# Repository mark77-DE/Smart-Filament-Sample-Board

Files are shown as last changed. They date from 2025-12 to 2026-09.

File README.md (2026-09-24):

<p align="center">
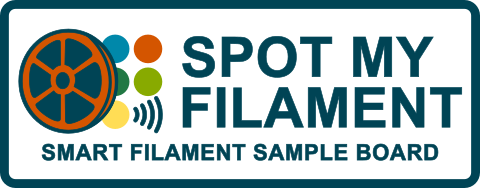
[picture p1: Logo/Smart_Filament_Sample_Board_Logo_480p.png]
Smart Filament Sample Board Logo
  
</p>

<h1 align="center">Smart Filament Sample Board</h1>
<p align="center"><i>Spot My Filament — finde jedes Filament-Sample per NFC-Tag auf einen Blick.</i></p>

<p align="center">
  
  
  
</p>

<p align="center">
  🇩🇪 <strong>Deutsch</strong> &nbsp;|&nbsp; 🇬🇧 <a href="./README_EN.md">English</a>
</p>

---

## Inhaltsverzeichnis

* [Funktionsweise](#funktionsweise)
* [Benötigte Hardware](#benötigte-hardware)
* [Galerie](#galerie)
* [Erste Schritte](#erste-schritte)
* [Dokumentation](#dokumentation)
* [Mitmachen](#mitmachen)
* [Lizenz](#lizenz)

## Funktionsweise

Workflow basierend auf einer eigenen JSON-Datenbank auf dem ESP32:

1. NFC-Tag wird über den NFC-Reader gelesen.
2. Der ESP32 fragt die Datenbank ab und stellt die Daten auf dem Display dar.
3. Die entsprechende LED leuchtet auf und zeigt den Lagerplatz des Samples an.
4. Ein Klick im WebIF zeigt ebenfalls, wo das Filament-Sample lagert.

Zusätzlich gibt es eine Anbindung an **Home Assistant** via HA-Discovery und MQTT:

Der ESP32 sendet das ausgewählte Filament (per NFC-Tag oder Klick im WebIF) an Home Assistant. LEDs und Display lassen sich per HA ein-/ausschalten, der ESP übermittelt den Status zurück.

## Benötigte Hardware

Siehe [Hardware-Dokumentation](./docs/hardware.md).

## Galerie

<p align="center">
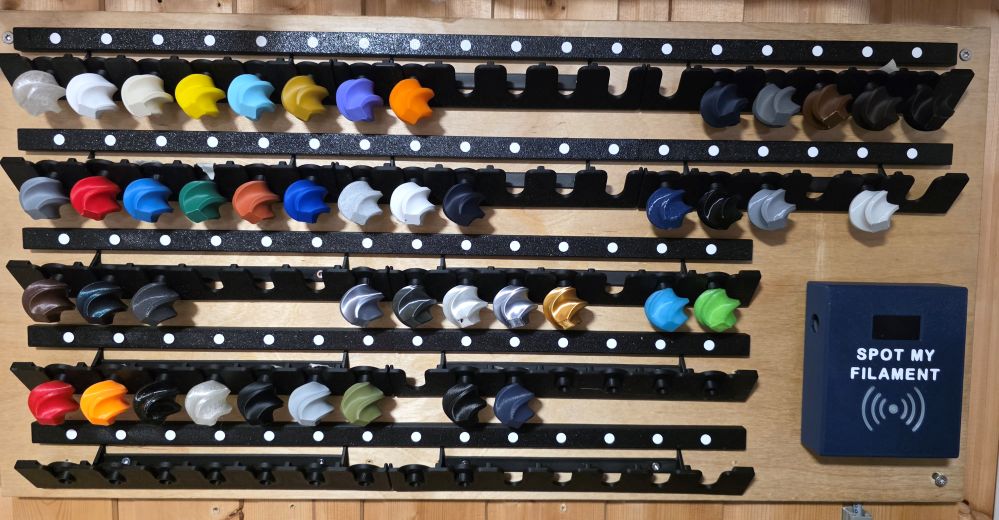
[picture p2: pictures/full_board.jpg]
Fertiges Board
  
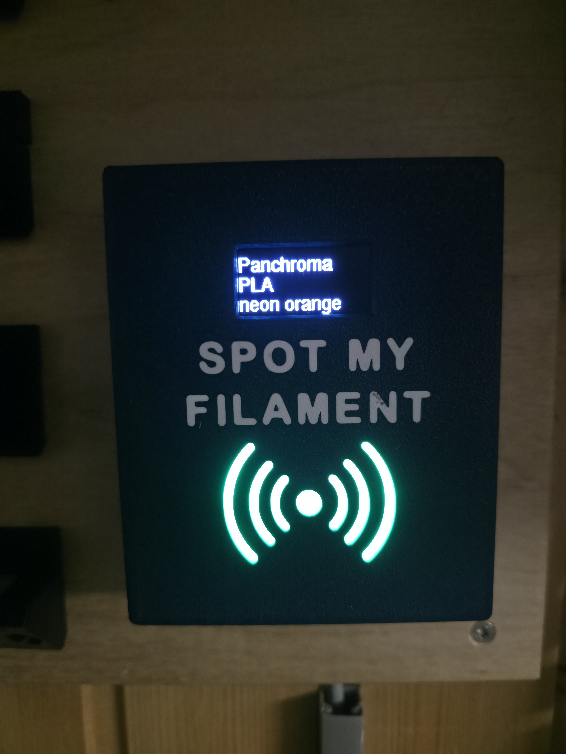
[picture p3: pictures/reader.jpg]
Display/Reader
    
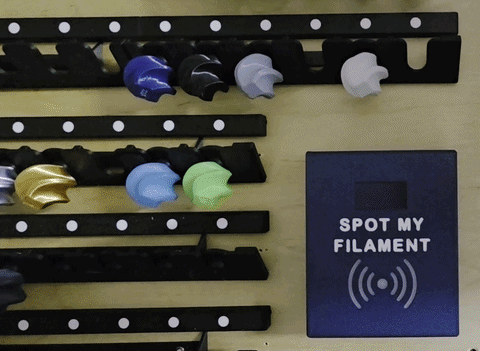
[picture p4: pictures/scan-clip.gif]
  <br>
  <sub>Fertig aufgebautes Board</sub>
</p>

<p align="center">
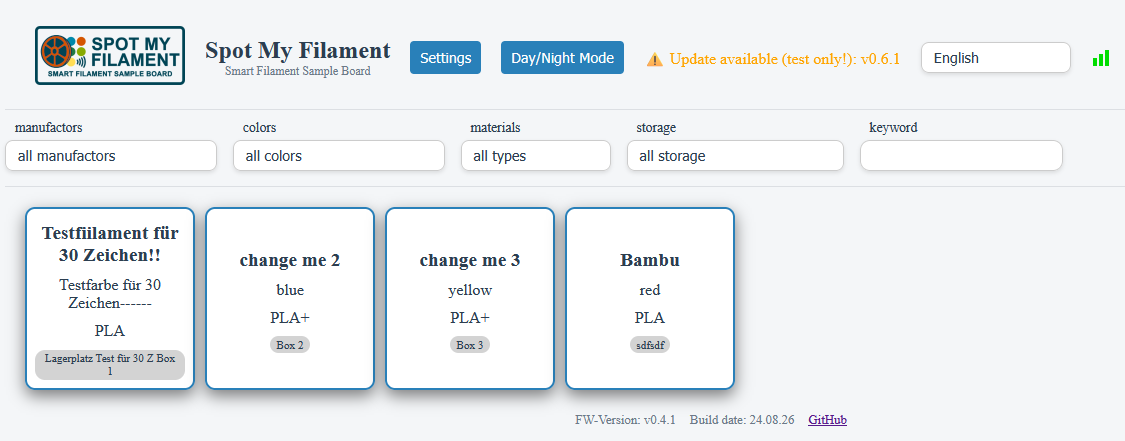
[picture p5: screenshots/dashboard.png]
Dashboard Daymode
  
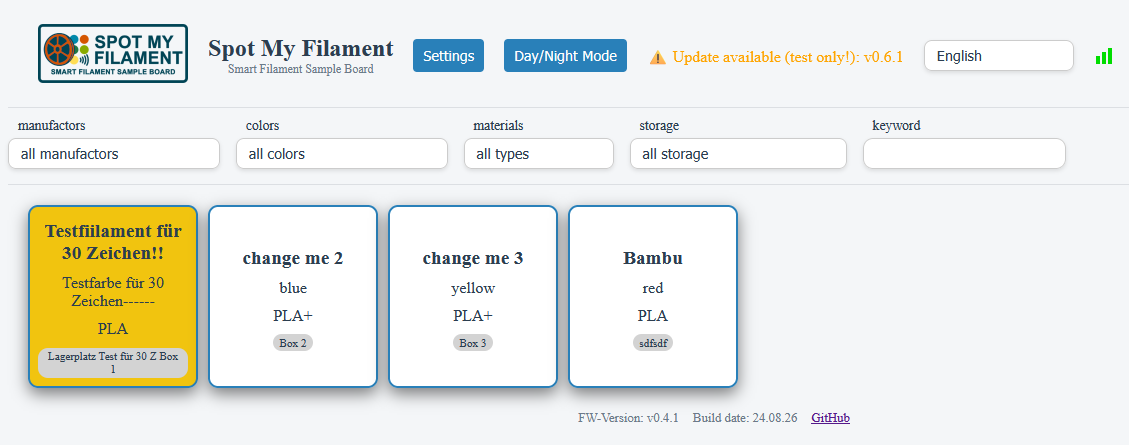
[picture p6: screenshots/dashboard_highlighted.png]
Dashboard Highlighted
  <br>
  <sub>Home-Assistant-Dashboard: Übersicht (links) und markiertes Sample (rechts)</sub>
</p>

## Erste Schritte

Kurzfassung — die ausführliche Anleitung steht in [`docs/setup.md`](docs/setup.md).

1. Hardware gemäß [`docs/hardware.md`](docs/hardware.md) verdrahten.
2. Firmware aus [`ESP32-Webserver`](ESP32-Webserver) auf den ESP32 flashen (siehe [`docs/setup.md`](docs/setup.md)).
3. WLAN-Zugangsdaten konfigurieren.
4. Optional: MQTT und Home-Assistant-Integration aktivieren (Auto-Discovery).
5. NFC-Tags anlegen und Filament-Samples zuordnen, siehe [`docs/usage.md`](docs/usage.md).

## Dokumentation

Ausführliche Anleitungen findest du im [`docs/`](docs) Ordner:

| Dokument | Inhalt |
| --- | --- |
| [`docs/hardware.md`](docs/hardware.md) | Verkabelung, Pinbelegung, Schaltplan |
| [`docs/setup.md`](docs/setup.md) | Firmware flashen, Konfiguration, Home-Assistant-Setup |
| [`docs/usage.md`](docs/usage.md) | Alltägliche Bedienung, NFC-Tags anlegen, WebIF |
| [`docs/3d-print.md`](docs/3d-print.md) | 3D-Druckteile aus [`3D-Daten`](3D-Daten), Druckeinstellungen |

<!-- Sammlung offener Notizen/Ideen liegt aktuell in Notes/ – ggf. dort verlinken -->

## Mitmachen

Contributions, Issues und Feature-Wünsche sind willkommen!

Schau gerne im [Issues-Tab](https://github.com/mark77-DE/Smart-Filament-Sample-Board/issues) vorbei.

<!-- TODO: falls gewünscht, CONTRIBUTING.md ergänzen und hier verlinken -->

## Lizenz

Dieses Projekt steht unter der [GPL-3.0 Lizenz](LICENSE).

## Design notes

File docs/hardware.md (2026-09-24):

# Hardware & Verkabelung

Diese Seite beschreibt den Aufbau des Smart Filament Sample Boards.

## Stückliste

| Komponente | Menge | Hinweise | Links |
|---|---|---|---|
| ESP-32 Devkit V1 **oder** ESP32-S3 Super Mini | 1 | | |
| PN532 NFC-Reader | 1 | | |
| WS2812B **oder**<br>SK6812 **oder**<br>SK6812W LEDs | 4×3 (Standard) NFC-Symbol<br>Plus Anzahl Samples | für Hintergrundbeleuchtung des NFC Symbols,<br> laut KI bis 150 LEDs je nach eigenem Setup<br>Abstand der LEDs sollte 33mm betragen, also 30LEDs/m | |
| 1.3" I2C Display 128×64 SH1106 **oder** 1.9" TFT ST7789 | 1 | | |
| Taster | optional | | |
| Buzzer | optional | | |
| Ntag215 | bis 150 | DieStückzahl sollte min. zur Anzahl der geplanten Samples passen | [AliExpress](https://de.aliexpress.com/item/1005006375989905.html) |
| Netzteil | 1 | <!-- TODO: Spannung/Stromstärke --> | |

## Pinbelegung

Die Pinbelegung ist, je nach verwendeten Controllertyp und Display, unterschiedlich.
Für die kompilierten Binaries gibt es feste Vorgaben, wer selbst kompiliert, kann das in der platformio.ini entsprechend modifizieren.

Für den weit verbreiteten Standard typ, dem ESP32 Devkit V1 gillt folgendes pinout:

### ESP32 OLED Variante
| ESP32 Pin | Verbunden mit | Funktion |
|---|---|---|
| GPIO 4 | LEDs | Samples |
| GPIO 15 | LEDs | NFC-Symbol |
| GPIO 18 | SPI/SCK | NFC-Reader |
| GPIO 19 | SPI/MISO | NFC-Reader |
| GPIO 21 | SDA | OLED |
| GPIO 22 | SCL | OLED |
| GPIO 23 | SPI/MOSI | NFC-Reader |
| GPIO 26 | PN532 CS | NFC-Reader |
| GPIO 32 | Button | optional |
| GPIO 33 | Buzzer | optional |

### ESP32-S3 OLED Variante
*(getestet mit ESP32-S3 Zero)*

| ESP32-S3 Pin | Verbunden mit | Funktion |
|---|---|---|
| GPIO 1 | LEDs | NFC-Symbol |
| GPIO 2 | LEDs | Samples |
| GPIO 3 | SPI/SCK | NFC-Reader |
| GPIO 4 | SPI/MISO | NFC-Reader |
| GPIO 5 | SPI/MOSI | NFC-Reader |
| GPIO 6 | PN532 CS | NFC-Reader |
| GPIO 7 | Button | optional |
| GPIO 8 | Buzzer | optional |
| GPIO 12 | SCL | OLED |
| GPIO 13 | SDA | OLED |

### ESP32 ST7789 Variante
| ESP32 Pin | Verbunden mit | Funktion |
|---|---|---|
| GPIO 4 | LEDs | Samples |
| GPIO 5 | TFT CS | ST7789 Display |
| GPIO 12 | NFC_MISO | NFC-Reader |
| GPIO 13 | NFC_MOSI | NFC-Reader |
| GPIO 14 | NFC_SCK | NFC-Reader |
| GPIO 15 | LEDs | NFC-Symbol |
| GPIO 26 | PN532 CS | NFC-Reader |
| GPIO 27 | TFT RST | ST7789 Display |
| GPIO 32 | TFT DC | ST7789 Display |
| GPIO 33 | Buzzer | optional |

### ESP32-S3 ST7789 Variante
| ESP32 Pin | Verbunden mit | Funktion |
|---|---|---|
| GPIO 4 | LEDs | Samples |
| GPIO 5 | TFT CS | ST7789 Display |
| GPIO 12 | NFC_MISO | NFC-Reader |
| GPIO 13 | NFC_MOSI | NFC-Reader |
| GPIO 14 | NFC_SCK | NFC-Reader |
| GPIO 15 | LEDs | NFC-Symbol |
| GPIO 25 | Button | optional |
| GPIO 26 | PN532 CS | NFC-Reader |
| GPIO 27 | TFT RST | ST7789 Display |
| GPIO 32 | TFT DC | ST7789 Display |
| GPIO 33 | Buzzer | optional |
| – | TFT MISO | nicht verbunden |

## Schaltplan / Wiring-Diagramm

<!-- TODO: Bild einbinden, z. B. aus Fritzing oder handgezeichnet
![Wiring Diagram](../pictures/wiring.png)
-->

## Aufbauhinweise

<!-- TODO: Besonderheiten beim Zusammenbau, z. B.:
- Reihenfolge der LED-Kette
- Stromversorgung bei vielen LEDs (separates Netzteil? Sicherung?)
- Gehäuse / mechanischer Aufbau, Verweis auf 3D-Daten
-->

Optimalfall: Das Netzteil sollte von der Leistung her zur Anzahl der LEDs passen wobei jede LED max. 60mA ziehen könnte..
Relaistisch (ohne Garantie): Durch die Limitierung der Brightness und der Tatsache, dass nie alle LEDs zeitgleich leuchten, kann das Netzteil auch kleiner ausgeführt werden. Für eine Testaufbau mit z.B. 16 LEDs reicht die Versorgung über edn ESP völlig aus.

Siehe auch: [`3d-print.md`](3d-print.md) für die gedruckten Gehäuseteile.

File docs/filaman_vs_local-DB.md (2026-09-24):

# Workflow: Lokale DB (filaments.json) vs. FilaMan-DB

Diese Seite beschreibt, wann das Smart Filament Sample Board auf die **lokale
`filaments.json`** (LittleFS) zugreift und wann es live gegen die
**FilaMan-API** abfragt — inklusive Sync-Mechanismus.

## Grundprinzip

| | Lokale DB (`filaments.json`) | FilaMan-DB (live) |
|---|---|---|
| Quelle | LittleFS auf dem ESP32 | FilaMan-Server (`server-ip:port`) |
| Inhalt | vendor, type, color, ledIndex, info1 (Bestand), info2 (Shop-URL) | Alle Felder inkl. `storage` (Lagerort) |
| Aktualisierung | Manuelle Pflege per WebIF | Immer aktuell (Live-Abfrage) |
| Geschwindigkeit | Sehr schnell (lokal) | Abhängig von Netzwerk/API-Latenz |
| Warum getrennt? | Stabile Stammdaten, selten geändert | Lagerort ändert sich häufig (AMS/Bambuddy-Zuordnung) und wäre in lokaler DB schnell veraltet |

Der Lagerort (`storage`) wird bewusst **nicht** synchronisiert, sondern immer
live abgefragt, da er sich zu oft ändert.

## Workflow 1: NFC-Scan am Sample Board (Nutzung)

```mermaid
flowchart TD
    A[Nutzer scannt NFC-Tag am Sample Board] --> B{sampleboard_uid bekannt?}
    B -- "Nein" --> Z[Fehleranzeige: UID nicht gefunden]
    B -- "Ja, in lokaler DB" --> C[Lade Stammdaten aus filaments.json:<br/>vendor, type, color, ledIndex, info1, info2]
    C --> D[LED am ledIndex ansteuern]
    C --> E{Netzwerk verfügbar?}
    E -- "Nein" --> F[Anzeige nur mit Stammdaten<br/>Lagerort: 'nicht verfügbar']
    E -- "Ja" --> G[Live-Query an FilaMan:<br/>filament_id -> zugehörige Spulen -> Lagerorte]
    G --> H[Lagerorte aggregieren<br/>sortiert nach Restbestand]
    H --> I[Vollständige Anzeige:<br/>Stammdaten + aktueller Lagerort]
```

**Kernidee:** Die lokale DB liefert sofort die stabilen Anzeigedaten und
steuert die LED, unabhängig vom Netzwerk. Der Lagerort wird nur bei
Bedarf live nachgeladen und ergänzt die Anzeige, sobald er verfügbar ist.

## Workflow 2: Sync der lokalen DB (Wartung)

```mermaid
flowchart TD
    A[Nutzer löst Sync aus<br/>WebIF-Button oder Hardware-Taste] --> B[Login an FilaMan-API<br/>POST /auth/login -> Cookie session_id]
    B --> C[GET /api/v1/filaments<br/>alle Filamente mit gesetztem sampleboard_uid]
    C --> D[Für jedes Filament Custom-Field<br/>sampleboard_led auslesen -> ledIndex]
    D --> E[Für jedes Filament zugehörige Spulen<br/>abfragen: Anzahl + Restgewicht summieren]
    E --> F[Feld-Mapping:<br/>vendor = manufacturer.name<br/>type = material_type<br/>color = manufacturer_color_name<br/>info1 = 'X Spulen mit Y g Restgewicht'<br/>info2 = shop_url]
    F --> G[filaments.json auf LittleFS schreiben/überschreiben]
    G --> H[Sync abgeschlossen -> Bestätigung im WebIF]
```

**Wichtig:** Der Sync läuft **nicht automatisch** bei jedem Boot, sondern nur
auf explizite Nutzeranforderung, um unnötige API-Last und Inkonsistenzen zu
vermeiden.

## Entscheidungslogik im Code (Kurzfassung)

```mermaid
flowchart LR
    A[UID gescannt] --> B[Lookup in filaments.json]
    B --> C[Stammdaten + LED sofort]
    C --> D{Storage-Info gewünscht?}
    D -- "Ja" --> E[Live-Call FilaMan]
    D -- "Nein / offline" --> F[Fertig ohne Lagerort]
    E --> G[Fertig mit Lagerort]
```

## Offene Punkte

- Workaround für den FilaMan-Bug bei der Custom-Field-Suche auf
  `/api/v1/filaments` bleibt bestehen, bis der Fix im Upstream-Projekt
  gemergt ist.

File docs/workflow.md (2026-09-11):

# Dev- & Release-Workflow — Smart Filament Sample Board

## Überblick

Zwei getrennte Pfade:

- **`dev_release.py`** — lokale Testbuilds, OTA Self-Update gegen einen simulierten Testserver, kein Git-Tag, kein GitHub Release.
- **`release.py`** — echtes, öffentliches Release (Git-Tag, GitHub Pre-/Release, Webinstaller-Update).

Versionsnummern werden **nicht** manuell gepflegt, sondern automatisch von `tools/git_version.py` erzeugt (läuft als PlatformIO `pre:`-Script bei jedem Build).

---

## 1. Entwickeln auf `dev` (oder einem Feature-Branch)

Normal weiterarbeiten, committen wie gewohnt.

```bash
git switch dev
# ... Änderungen ...
git add .
git commit -m "..."
```

Feature-Branches (z. B. `display`) zweigen von `dev` ab und funktionieren genauso — `dev_release.py` und `git_version.py` erkennen automatisch, dass es kein `main` ist.

---

## 2. Lokal testen mit `dev_release.py`

```bash
python tools/dev_release.py
# oder mit expliziter Test-Server-IP:
python tools/dev_release.py --server-ip 172.16.0.123
python tools/dev_release.py --server-ip 172.16.0.123 --port 8080
```

Was dabei passiert:

1. **Branch-Check**: bricht ab, wenn der aktuelle Branch `main` ist (Sicherheitsnetz, damit nie versehentlich ein "Test"-Build von `main` aus läuft).
2. **`ota_local_server_generated.h`** wird geschrieben (Testserver-IP/-Port), entweder automatisch erkannt oder per `--server-ip` vorgegeben.
3. **Build** der vier `*_dev`-Envs (`esp32_dev`, `esp32-st7789_dev`, `esp32-s3_dev`, `esp32-s3-st7789_dev`) — diese haben zusätzlich `-D OTA_DEBUG_LOCAL_SERVER` gesetzt.
4. **Kopieren** der vier `firmware.bin`-Dateien nach `tools/local_testserver/v9.9.9/` mit festen Namen:
   - `esp32-sh1106-firmware.bin`
   - `esp32-st7789-firmware.bin`
   - `esp32-s3-sh1106-firmware.bin`
   - `esp32-s3-st7789-firmware.bin`

Danach den simulierten Testserver in diesem Ordner starten (z. B. `python -m http.server 8000` in `tools/local_testserver/v9.9.9/`) und am Gerät den OTA Self-Update testen.

`FIRMWARE_VERSION` in diesem Build lautet automatisch z. B. `v0.4.11-dev.3` (auf `dev`) oder `v0.4.11-dev.3-disp` (auf einem Feature-Branch namens `display`).

---

## 3. Release bauen

```bash
git switch main
git merge dev              # WICHTIG: main auf den aktuellen dev-Stand bringen
python tools/release.py 0.4.12
```

`release.py` übernimmt: Git-Tag setzen, Firmware bauen (normale Envs ohne `OTA_DEBUG_LOCAL_SERVER`, also mit der echten GitHub-URL), Webinstaller-Manifeste aktualisieren, GitHub Release erstellen, pushen.

---

## 4. `dev` wieder auf den aktuellen Stand bringen

**Nicht vergessen — sonst zählt `git_version.py` ab dem alten Tag weiter:**

```bash
git switch dev
git merge main
```

Ohne diesen Schritt bleibt der zuletzt getaggte Release-Commit für `dev` unerreichbar, und `git_version.py` fällt auf den vorletzten Tag zurück (z. B. `v0.4.9-dev.N` statt `v0.4.11-dev.N`).

---

## Versionslogik (`tools/git_version.py`)

Läuft bei **jedem** Build (alle Envs, egal ob `release.py` oder `dev_release.py`).

| Branch | `FIRMWARE_VERSION` |
|---|---|
| `main` | exakt der letzte Tag, z. B. `v0.4.11` |
| `dev` | `v0.4.11-dev.N` (N = Commits seit dem letzten *echten* Tag) |
| Feature-Branch (z. B. `display`) | `v0.4.11-dev.N-disp` (Branchname auf 4 Zeichen gekürzt) |

Wichtig: Alte `-dev`-Tags aus dem ursprünglichen Workflow (z. B. `v0.4.11-dev`, `v0.4.12-dev`) werden beim Ermitteln des Basis-Tags bewusst ausgeschlossen (`--exclude "*-dev*"`), damit sie die Zählung nicht verfälschen. Sie können bei Gelegenheit aufgeräumt werden, stören aber nicht mehr:

```bash
git tag -d v0.4.11-dev
git push origin :refs/tags/v0.4.11-dev
```

`STABLE_BRANCH` ist in `git_version.py` als `"main"` hinterlegt — falls der Produktions-Branch anders heißt, dort anpassen.

---

## Beteiligte Dateien

| Datei | Zweck | Wird committet? |
|---|---|---|
| `tools/git_version.py` | Generiert `include/version_info.h` bei jedem Build (Version, Git-Hash, Build-Datum) | Ja |
| `tools/dev_release.py` | Lokaler Testbuild + Kopie nach `local_testserver/` | Ja |
| `tools/release.py` | Echtes Release (Tag, Build, GitHub Release, Webinstaller) | Ja |
| `include/version_info.h` | Auto-generiert, nicht von Hand pflegen | Nein (gitignore) |
| `include/ota_local_server_generated.h` | Auto-generiert von `dev_release.py`, enthält lokale Test-Server-URL | Nein (gitignore) |
| `tools/local_testserver/v9.9.9/` | Ablage der Testbuilds für OTA Self-Update Tests | Nein (gitignore empfohlen) |

`.gitignore`-Einträge, falls noch nicht vorhanden:

```
include/version_info.h
include/ota_local_server_generated.h
tools/local_testserver/
```

---

## platformio.ini — relevante Envs

```ini
; Normale Produktions-Envs (nutzt release.py)
[env:esp32]
...
[env:esp32-st7789]
...
[env:esp32-s3]
...
[env:esp32-s3-st7789]
...

; Dev/Test-Envs (nutzt dev_release.py) — je extends + OTA_DEBUG_LOCAL_SERVER
[env:esp32_dev]
extends = env:esp32
build_flags =
    ${env:esp32.build_flags}
    -D OTA_DEBUG_LOCAL_SERVER

[env:esp32-st7789_dev]
extends = env:esp32-st7789
build_flags =
    ${env:esp32-st7789.build_flags}
    -D OTA_DEBUG_LOCAL_SERVER

[env:esp32-s3_dev]
extends = env:esp32-s3
build_flags =
    ${env:esp32-s3.build_flags}
    -D OTA_DEBUG_LOCAL_SERVER

[env:esp32-s3-st7789_dev]
extends = env:esp32-s3-st7789
build_flags =
    ${env:esp32-s3-st7789.build_flags}
    -D OTA_DEBUG_LOCAL_SERVER
```

Alle Envs teilen sich:

```ini
extra_scripts = pre:tools/git_version.py
```

---

## Kurz-Spickzettel

```bash
# --- Entwickeln ---
git switch dev
# ... arbeiten, committen ...
python tools/dev_release.py           # lokal testen (OTA gegen local_testserver)

# --- Releasen ---
git switch main
git merge dev
python tools/release.py 0.4.12

# --- Zurück zu dev ---
git switch dev
git merge main
```

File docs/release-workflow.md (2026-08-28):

# Release-Workflow (`tools/release.py`)

Dieses Script übernimmt den kompletten Ablauf von einer neuen Versionsnummer
bis zum fertigen GitHub Release: Git-Tag setzen, alle Firmware-Varianten
bauen, Dateien für den Webinstaller exportieren, Manifeste aktualisieren,
committen/pushen und ein GitHub Release mit allen Firmware-Dateien anlegen.

## Voraussetzungen

- [PlatformIO CLI](https://platformio.org/) (`pio`) im PATH — bei VSCode-Nutzung meist automatisch vorhanden
- [GitHub CLI](https://cli.github.com/) (`gh`) installiert **und** eingeloggt:
  ```powershell
  gh auth login
  ```
- Ein sauberer Git-Status (keine uncommitteten Änderungen) — das Script bricht sonst ab
- Das Script wird aus dem `ESP32-Webserver`-Ordner heraus aufgerufen (dort, wo auch `platformio.ini` liegt)

## Grundnutzung

```powershell
python tools/release.py 0.4.2
```

Das führt **alle sechs Schritte** hintereinander aus:

| Schritt | Was passiert |
|---|---|
| 1. Tag setzen | Legt lokal den Git-Tag `v0.4.2` an — **vor** dem Build, damit `git_version.py` die neue Versionsnummer in die Firmware einbettet |
| 2. Bauen | Baut alle Display-Varianten (App); baut LittleFS **nur einmal pro Chip-Familie** (ESP32, ESP32-S3), da der Dateisystem-Inhalt über alle Displays hinweg identisch ist |
| 3. Exportieren | Kopiert `firmware.factory.bin` + `firmware.bin` je Variante sowie die geteilten `littlefs.bin`-Dateien nach `docs/webinstaller/firmware/` |
| 4. Manifeste aktualisieren | Setzt die Versionsnummer und einen Cache-Busting-Parameter (`?v=...`) in allen `docs/webinstaller/manifests/*.json` sowie `ASSET_VERSION` in `index.html` |
| 5. Commit + Push | Committet die Änderungen in `docs/webinstaller/`, pusht den Commit und den Tag |
| 6. GitHub Release | Erstellt (oder aktualisiert) ein GitHub Release mit allen Firmware-Dateien als Assets |

## Welche Dateien wofür verwendet werden

| Datei | Verwendungszweck |
|---|---|
| `<variante>-firmware.factory.bin` | Für den **Webinstaller** — enthält Bootloader, Partitionstabelle und App in einer Datei, wird bei `0x0` geflasht |
| `<variante>-firmware.bin` | Für den **eingebauten OTA-Updater** im WebIF — reine App-Binärdatei zum manuellen Hochladen |
| `esp32-littlefs.bin` / `esp32-s3-littlefs.bin` | Dateisystem-Image, **einmal pro Chip-Familie**, wird von allen Display-Varianten dieser Familie geteilt (identischer Inhalt) |

Der Webinstaller selbst nutzt ausschließlich `firmware.factory.bin` + die geteilte `littlefs.bin` (siehe `docs/webinstaller/manifests/*.json`). Die einzelnen `firmware.bin`-Dateien sind **nicht** im Webinstaller verlinkt, sondern nur als Release-Asset für den manuellen OTA-Upload gedacht.

## Schalter (Flags)

| Flag | Wirkung |
|---|---|
| *(keiner)* | Kompletter Ablauf: Tag → Bauen → Exportieren → Manifeste → Commit/Push → Release |
| `--skip-build` | Überspringt Schritt 2 (Bauen) und nutzt die vorhandenen Dateien in `.pio/build/`. Sinnvoll, wenn kurz zuvor schon manuell gebaut wurde. |
| `--skip-release` | Führt nur Schritt 1–4 aus (Tag lokal, bauen, exportieren, Manifeste aktualisieren) — **kein** Commit, **kein** Push, **kein** GitHub Release. Zum risikofreien Testen, bevor etwas veröffentlicht wird. |
| `--release-only` | Überspringt Schritt 1–5 komplett und führt **nur** Schritt 6 (GitHub Release) aus. Für den Fall, dass Build/Commit/Push schon erfolgreich liefen und nur die Release-Erstellung fehlgeschlagen ist (z. B. weil `gh` noch nicht eingeloggt war). |

### Beispiele

```powershell
# Alles auf einmal
python tools/release.py 0.4.2

# Nur bauen und exportieren, um das Ergebnis lokal zu prüfen
python tools/release.py 0.4.2 --skip-release

# Build übernehmen, den Rest normal durchlaufen lassen
python tools/release.py 0.4.2 --skip-build

# Release nachträglich erstellen, weil "gh" beim ersten Versuch fehlte
python tools/release.py 0.4.2 --release-only
```

## Verhalten bei bereits existierendem Release

Läuft das Script mit derselben Versionsnummer ein zweites Mal (z. B. nach
einem Fehler oder um Assets zu aktualisieren), prüft Schritt 6 automatisch,
ob unter diesem Tag schon ein GitHub Release existiert:

- **Existiert noch nicht** → `gh release create` legt ein neues Release an.
- **Existiert bereits** → `gh release upload ... --clobber` lädt die Dateien
  hoch und überschreibt gleichnamige, bereits vorhandene Assets. Das Script
  bricht in diesem Fall **nicht** mehr mit einem Fehler ab.

## Typische Fehler und Lösungen

| Fehlermeldung | Ursache | Lösung |
|---|---|---|
| `FEHLER: Es gibt uncommittete Änderungen im Repo.` | Es liegen nicht committete Änderungen vor | Erst committen oder stashen, dann erneut versuchen |
| `FileNotFoundError` bei `gh` | GitHub CLI nicht installiert oder nicht im PATH des verwendeten Terminals | `winget install --id GitHub.cli`, danach neues Terminal öffnen |
| `To get started with GitHub CLI, please run: gh auth login` | `gh` ist installiert, aber nicht angemeldet | Einmalig `gh auth login` ausführen |
| `a release with the same tag name already exists` | Release wurde schon einmal erstellt (z. B. bei einem vorherigen, fehlgeschlagenen Lauf) | Passiert mit der aktuellen Script-Version nicht mehr — Assets werden automatisch per Upload ergänzt/überschrieben |
| `FEHLER: Build-Verzeichnis fehlt` / `FEHLER: firmware.bin fehlt` | Für eine Variante wurde noch nicht gebaut | `--skip-build` weglassen, damit das Script selbst baut, oder manuell `pio run -e <env>` ausführen |

## Wo die Versionsnummer eigentlich herkommt

Die Firmware selbst liest ihre Versionsangabe (`Firmware Version Info: v0.4.2`
im Boot-Log) über das Pre-Build-Script `tools/git_version.py` aus dem
aktuellsten Git-Tag aus. Deshalb setzt `release.py` den Tag **immer vor** dem
Build — wird die Reihenfolge vertauscht, kompiliert die Firmware weiterhin
mit der alten Versionsnummer, auch wenn das GitHub Release schon den neuen
Namen trägt.

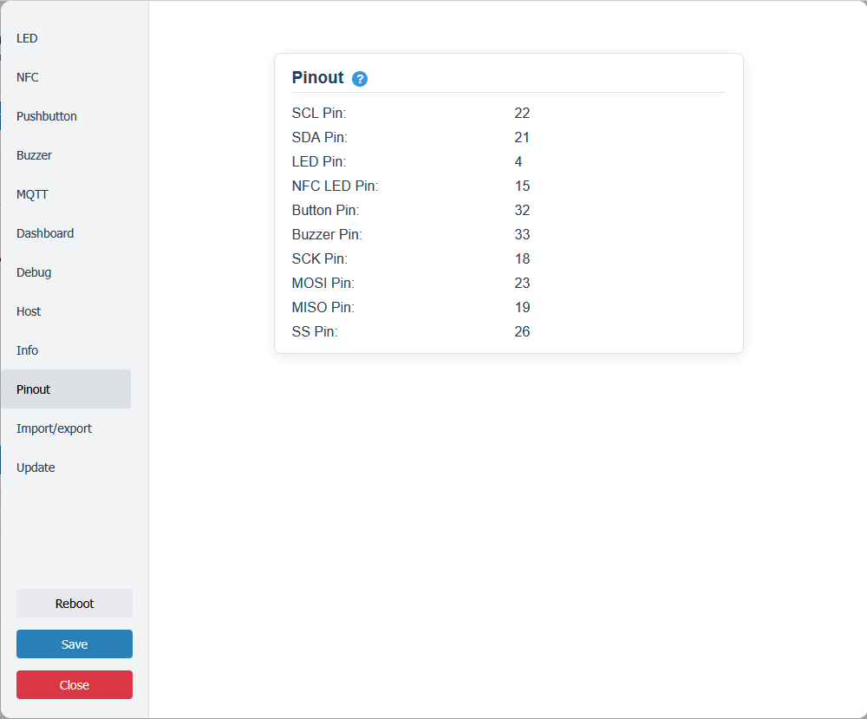
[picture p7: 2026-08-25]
screenshots/settings_pinout.png

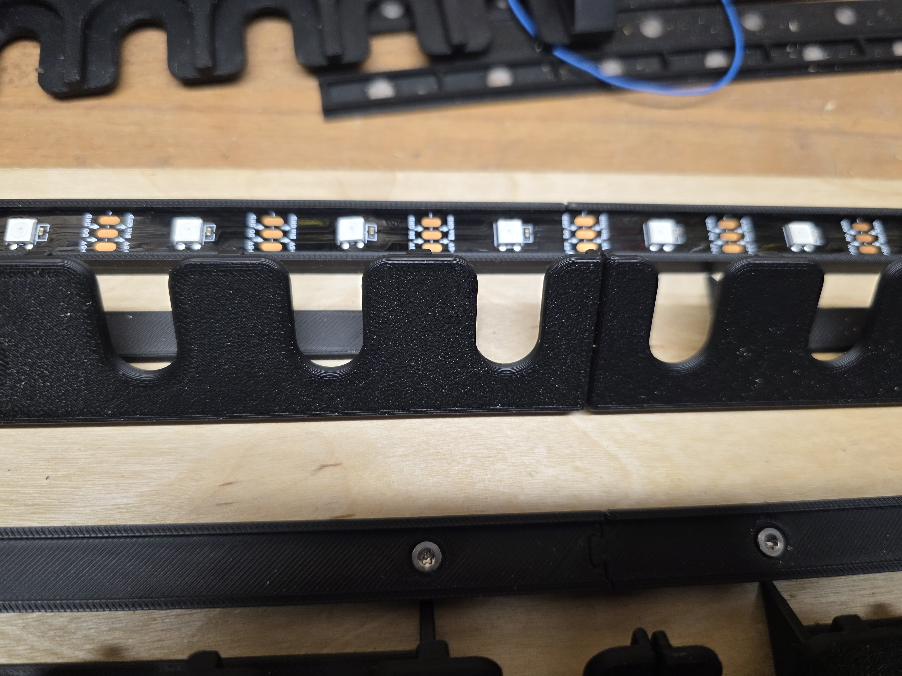
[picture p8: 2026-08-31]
pictures/led_strip.jpg

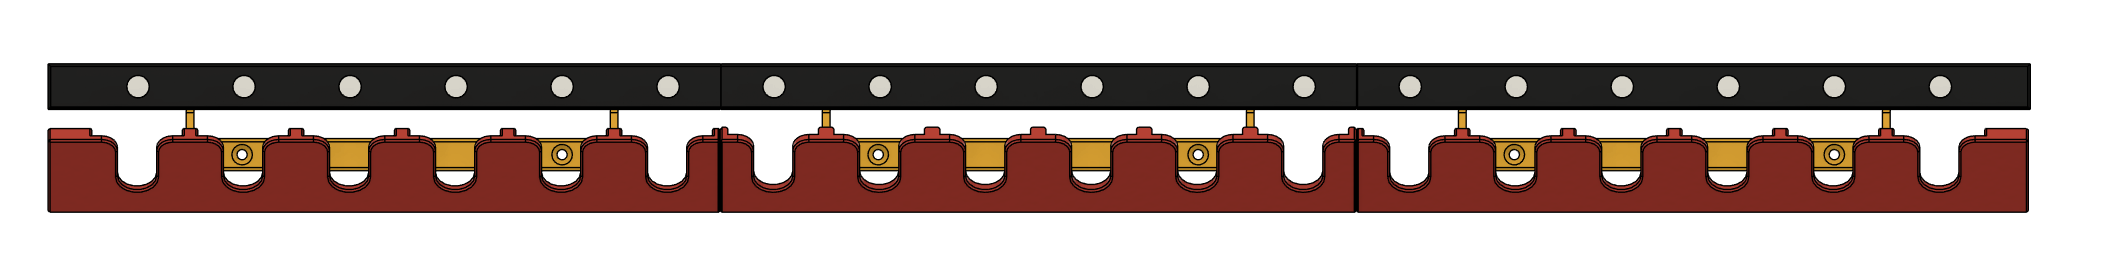
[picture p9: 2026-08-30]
screenshots/halter-3d_2.png

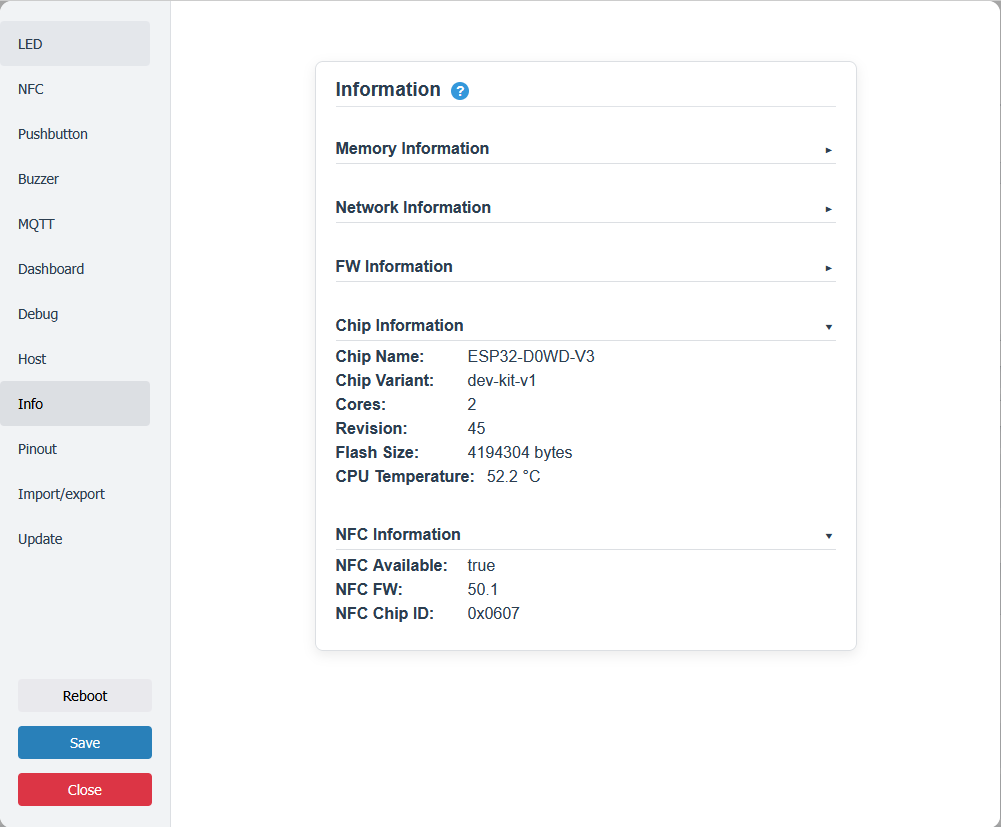
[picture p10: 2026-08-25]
screenshots/settings_info-2.png

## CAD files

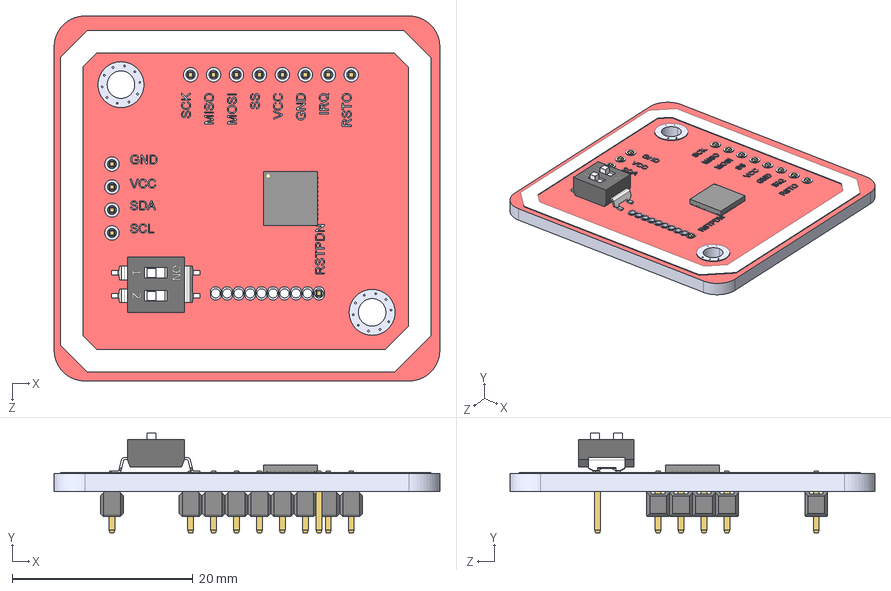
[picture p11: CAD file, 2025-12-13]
3D-Daten/CAD-Komponenten/PN532_NFC_Assembly.STEP
42.7 x 11.0 x 40.4 mm
NFC_MODULE_1
Pin Stand 2.54mm_1 x 12
QFN40 (6x6)_1
Switch_2_1
pin_my_1 x 13

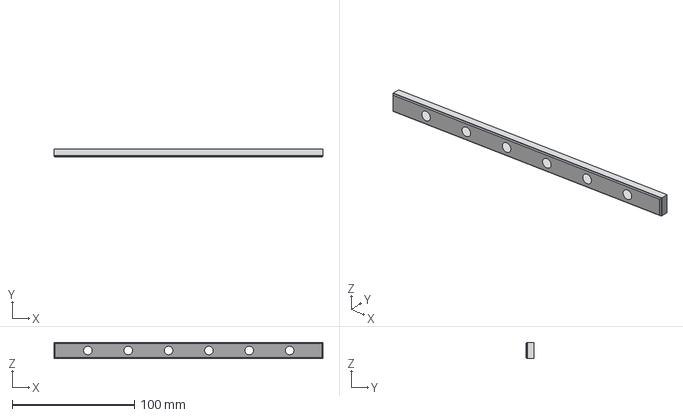
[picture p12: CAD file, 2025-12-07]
3D-Daten/CAD-Daten_Halter/Alte Version/LED-Halter.step
220.0 x 6.60 x 13.4 mm

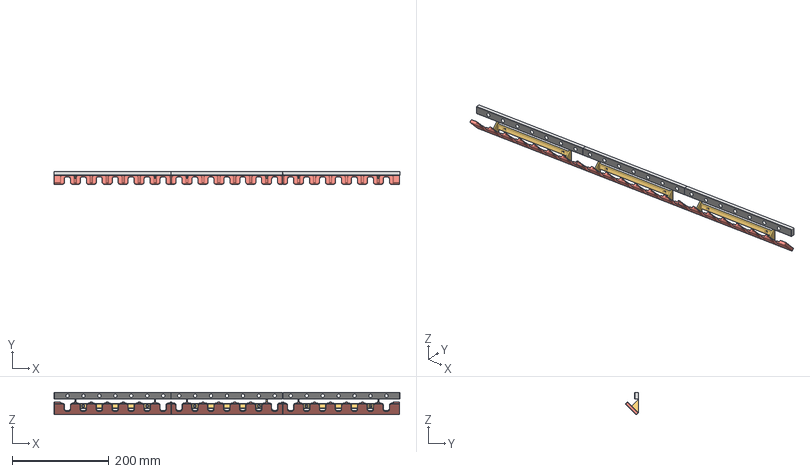
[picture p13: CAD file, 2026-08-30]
3D-Daten/CAD-Daten_Halter/FilamentSample_Regal_Halter_7x v2.step
716.0 x 26.4 x 46.2 mm
Deckel
HalterNeu

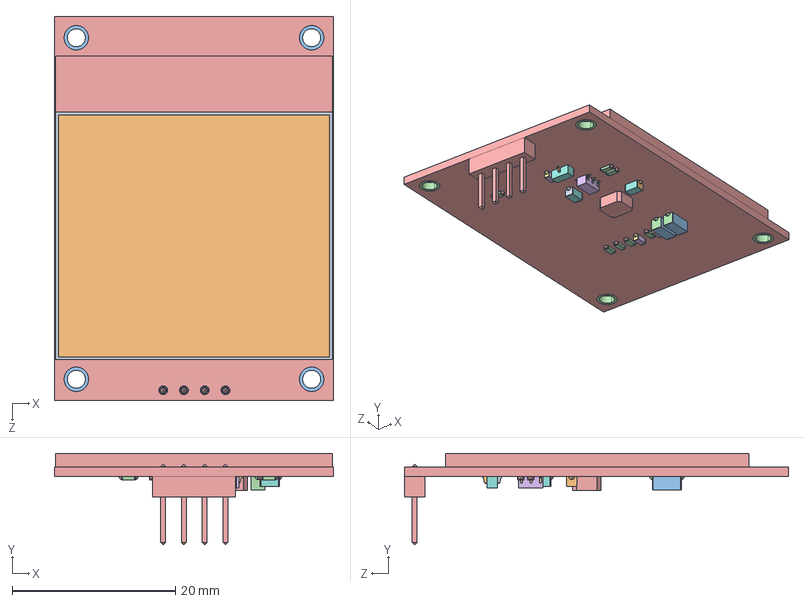
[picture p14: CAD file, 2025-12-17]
3D-Daten/CAD-Komponenten/SH1107_OLED_1_5.STEP
34.1 x 11.1 x 47.1 mm

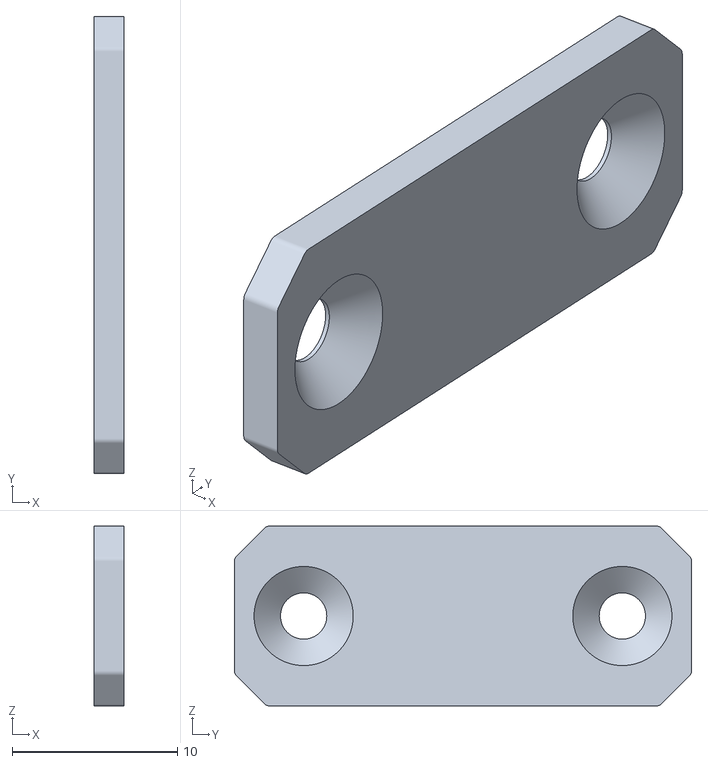
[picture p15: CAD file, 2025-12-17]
3D-Daten/CDU/CDU_Kolja_V3_USB_Cover.stl
1.80 x 27.7 x 10.9

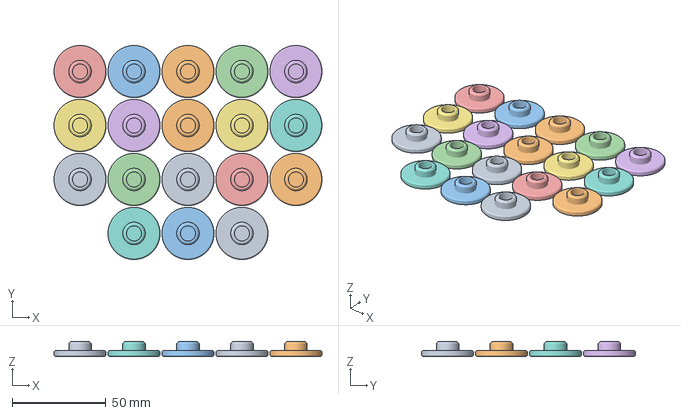
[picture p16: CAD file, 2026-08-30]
3D-Daten/Printfiles/Sample_Fuss.3mf
143.0 x 114.2 x 8.00 mm

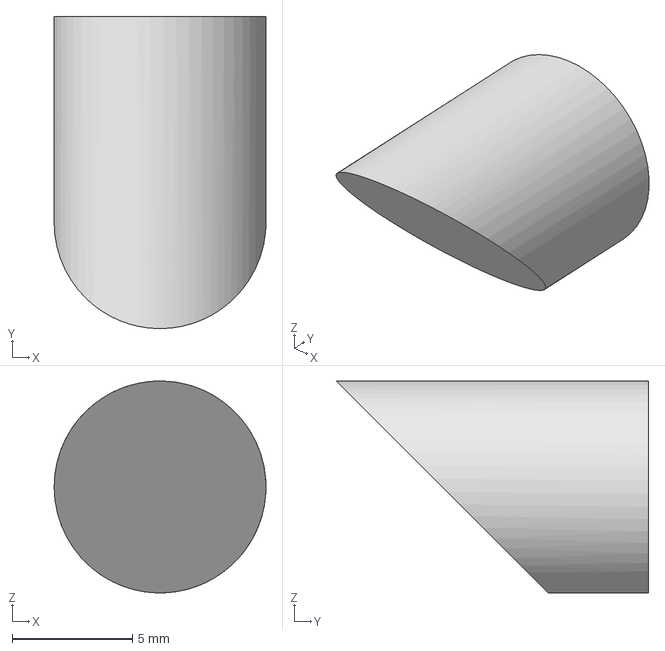
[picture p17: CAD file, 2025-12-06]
3D-Daten/CAD-Daten_Halter/Alte Version/SchraubenKappe.step
8.79 x 13.0 x 8.80 mm

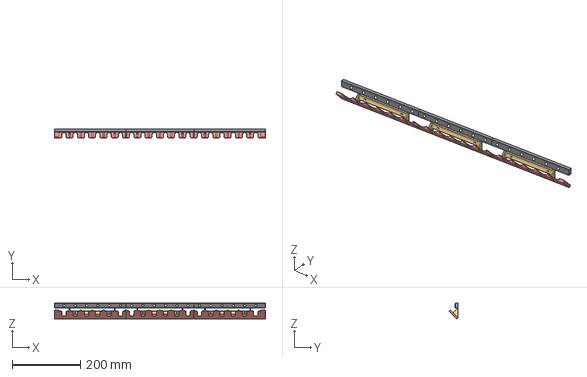
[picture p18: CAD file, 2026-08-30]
3D-Daten/CAD-Daten_Halter/FilamentSample_Regal_Halter_6x v3.step
617.0 x 26.4 x 46.2 mm
Deckel
HalterNeu

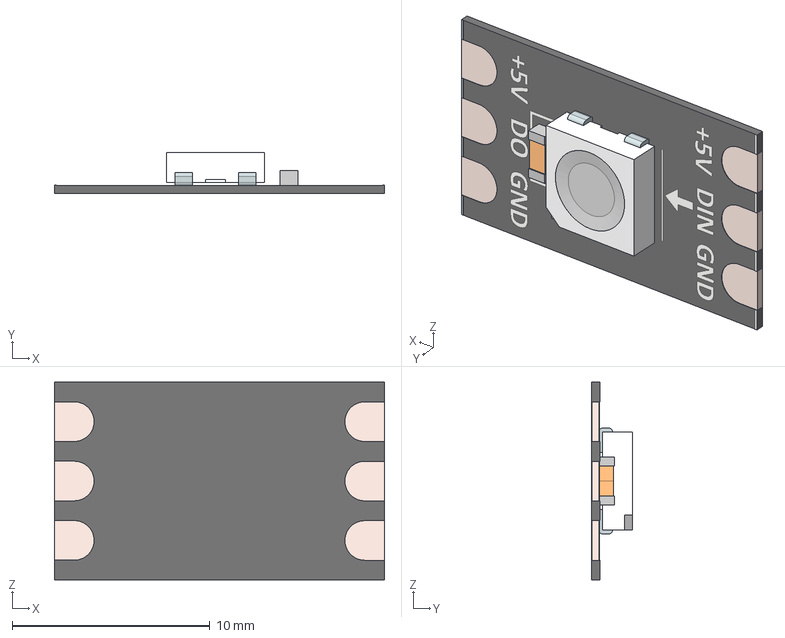
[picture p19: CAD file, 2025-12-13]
3D-Daten/CAD-Komponenten/WS2812B_60_LEDs.step
16.7 x 2.05 x 10.0 mm

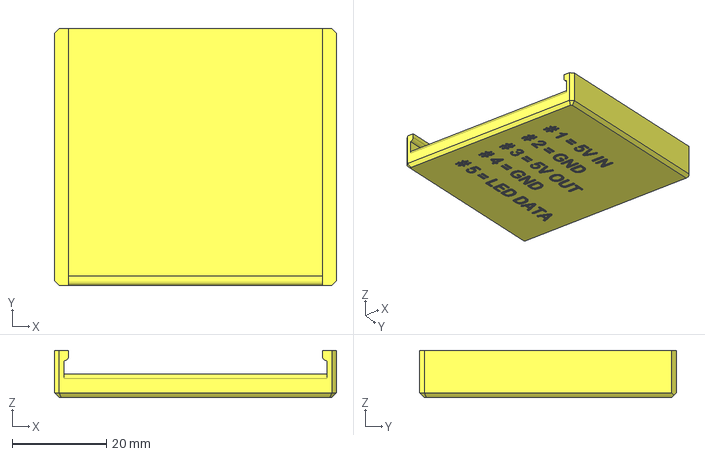
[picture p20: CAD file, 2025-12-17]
3D-Daten/CDU/WAGO Abdeckplatte beschriftet.stp
60.0 x 54.6 x 10.0 mm
WAGO Abdeckplatte
WAGO Beschriftung

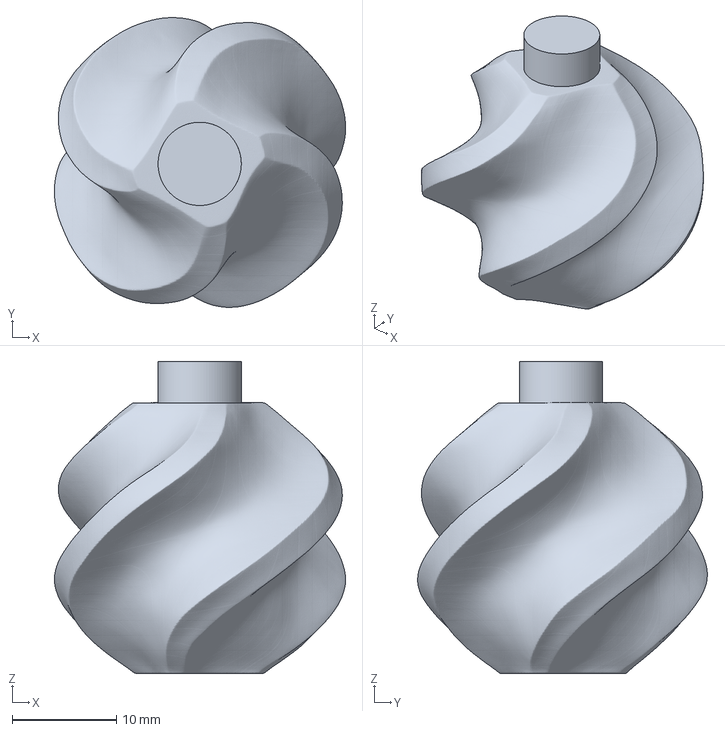
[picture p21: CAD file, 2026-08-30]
3D-Daten/Printfiles/ModifiedSample.3mf
28.0 x 27.9 x 30.0 mm

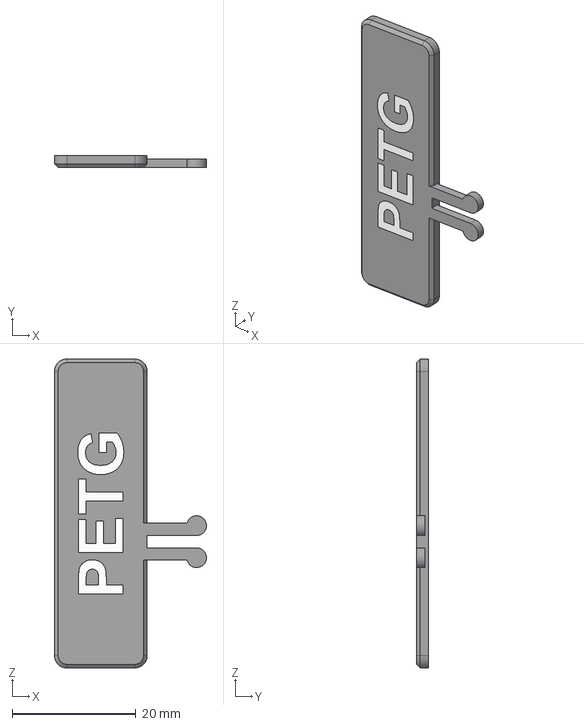
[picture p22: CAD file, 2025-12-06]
3D-Daten/CAD-Daten_Halter/Alte Version/Schild_PETG.step
24.6 x 2.00 x 50.0 mm

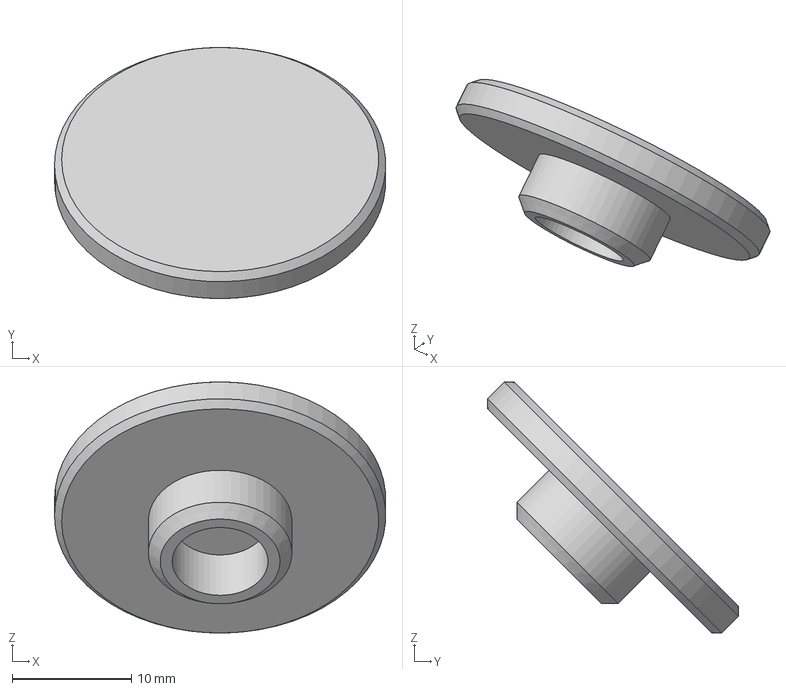
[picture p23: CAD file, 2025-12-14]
3D-Daten/CAD-Daten_Halter/SampleFuss_V2.0.stp
27.8 x 21.1 x 21.1 mm

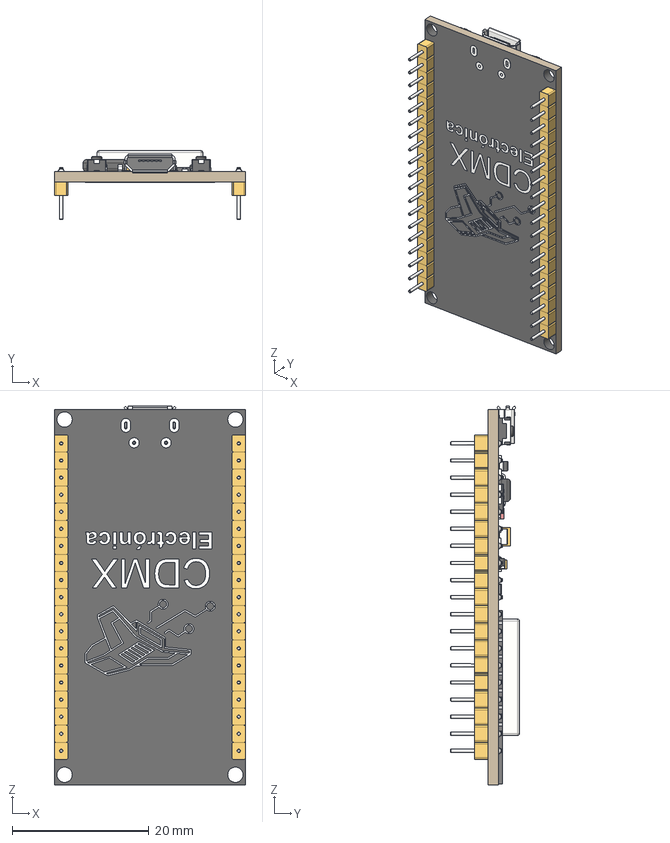
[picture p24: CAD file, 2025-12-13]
3D-Daten/CAD-Komponenten/ESP32_WROOM.step
28.0 x 10.1 x 55.5 mm
MicroUSB
esp32
AMS1173.3V
cp2102
Push_Bottom x 2
Diodo_K24
Cap_Tam_106
Cap_Tam_106C
Transistor_smd x 2
Led_red_0603
Cap_0603 x 7
Res_102
Res_123 x 3
Res_471 x 4
Res_512 x 2

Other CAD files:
3D-Daten/CDU/CDU_Kolja_V3_Wandhalterung_Schrauben.stl
3D-Daten/Printfiles/Filament-Sample-Board_6x.3mf
3D-Daten/CAD-Daten_Halter/Alte Version/Schild.step
3D-Daten/CAD-Komponenten/ESP32-C3.step
3D-Daten/CAD-Daten_Halter/Alte Version/FilamentSampleRegal v10.f3d
3D-Daten/CAD-Daten_Halter/Alte Version/FilamentSampleRegal v10.step
3D-Daten/CAD-Daten_Halter/Alte Version/Halter.step
3D-Daten/CAD-Daten_Halter/Alte Version/SampleFuss.step
3D-Daten/CAD-Daten_Halter/Alte Version/Schild_PETG-CF.step
3D-Daten/CAD-Daten_Halter/Alte Version/Schild_PLA-Plus.step
3D-Daten/CAD-Daten_Halter/Alte Version/Schild_PLA.step
3D-Daten/CAD-Daten_Halter/Alte Version/Schild_Spezial.step
3D-Daten/CAD-Komponenten/221-2411.stp
3D-Daten/CAD-Komponenten/Adafruit_NeoPixel_Stick_8.step
3D-Daten/CAD-Komponenten/OLED 2.42 V1.1 SSD1309.STEP
3D-Daten/CAD-Komponenten/OLED13_IIC.stp
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

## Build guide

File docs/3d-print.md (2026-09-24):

# 3D-Druckteile

### Auf dieser Seite gibt es eine kurze Übersicht zu den 3D-Druckteilen

Alle 3D-Druck- bzw. .step-Dateien liegen im Ordner [`3D-Daten`](../3D-Daten/).

Die 6er Version lässt sich noch auf dem A1-Mini drucken.

>Hinweis: Aktuell gibt es nur 6er und 7er Varianten, 4er und 5er sind in Planung.

## Dateiübersicht

| Dateiname | Info |
|---|---|
| [Filament-Sample-Board_6x.3mf](../3D-Daten/Printfiles/Filament-Sample-Board_6x.3mf) | Komplettpaket eine Zeile 3x6 Halter |
| [Filament-Sample-Board_7x.3mf](../3D-Daten/Printfiles/Filament-Sample-Board_7x.3mf) | Komplettpaket eine Zeile 3x7 Halter |
| [ModifiedSample.3mf](../3D-Daten/Printfiles/ModifiedSample.3mf) | Das bekannte Sample mit verkürztem Fuß |
| [Sample_Fuss.3mf](../3D-Daten/Printfiles/Sample_Fuss.3mf) | Der Fuß für die Samples |

## Wichtige Druckeinstellungen

Der Fuß benötigt eine **Druckpause bei Layer 12 bzw. 2,4mm Höhe.**
An der Stelle wird das NFC-Tag eingelegt und am Besten mit <b>seiner Klebefolie eingeklebt</b>, damit es sich im Druck nicht verschiebt.

<p align="center">
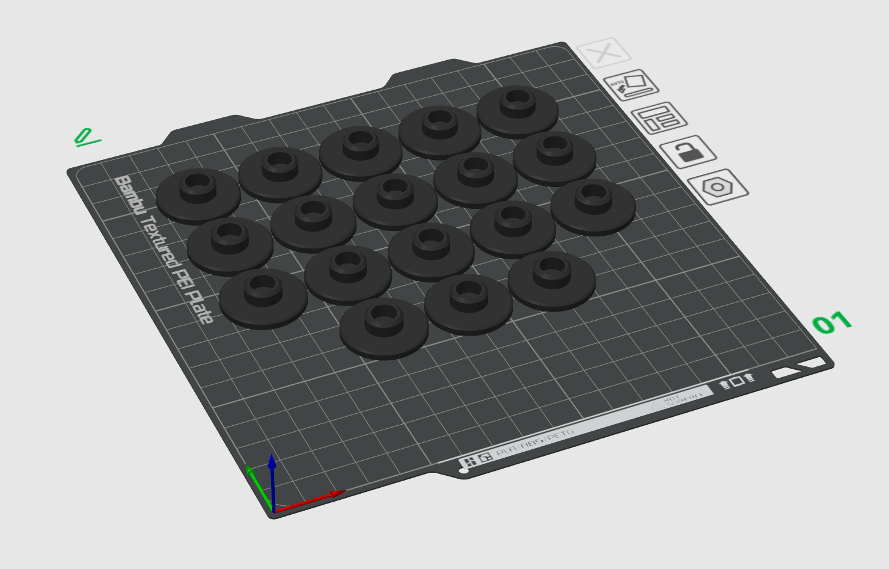
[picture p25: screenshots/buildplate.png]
buildplate
  
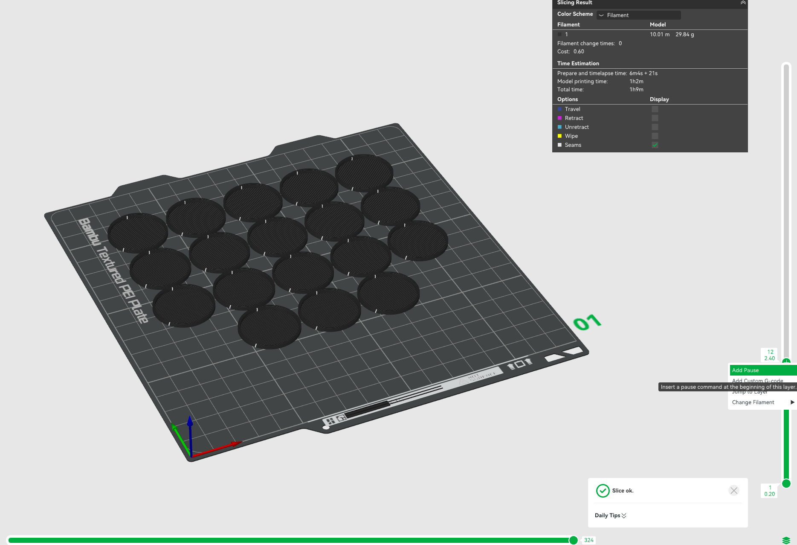
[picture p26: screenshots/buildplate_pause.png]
buildplate pause
  <br>
  <sub>Print Pause</sub>
</p>

Das Sample selbt sollte mit **0,16mm Layerhöhe** gedruckt werden, da die Farben besser zur Geltung kommen.
<p align="center">
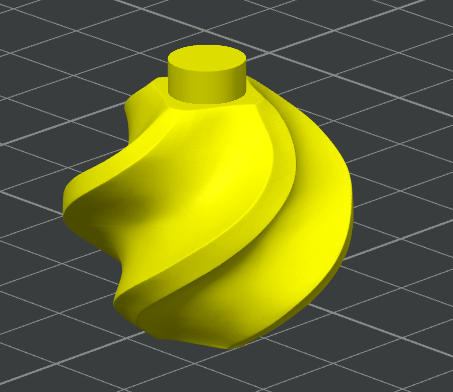
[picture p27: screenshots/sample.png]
sample
  <br>
  <sub>Sample</sub>
</p>

## Montagehinweise

Die Teile sind untereinander kompatibel.<br>
Die LED Halter haben "Puzzle-Nasen", damit sie aneinadergereiht werden können.<br>
Außerdem haben sie kleine Aussparung an der Unterseite, damit der Halter für den Träger besser ausgerichtet werden kann.

<table align="center">
  <tr>
    <td align="center">
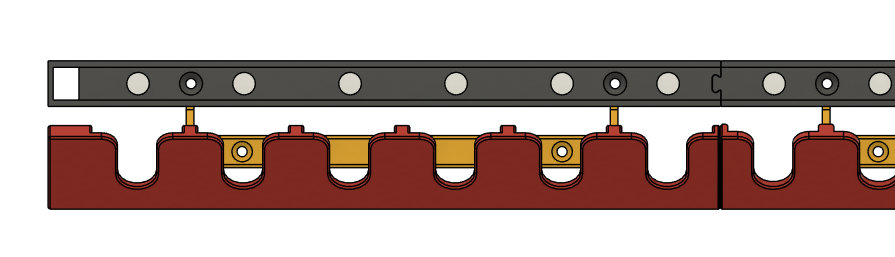
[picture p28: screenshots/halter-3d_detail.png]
detail
      <br>
      <sub>Puzzle Nase</sub>
    </td>
    <td align="center">
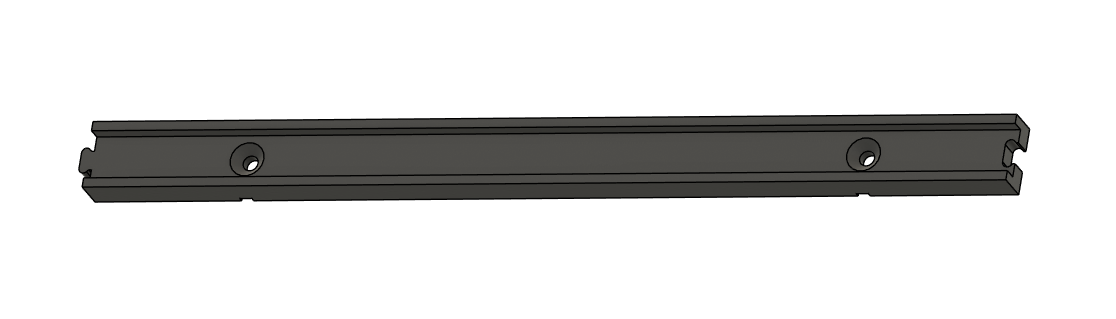
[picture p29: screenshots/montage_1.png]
montage
      <br>
      <sub>Aussparung LED-Halter</sub>
    </td>
  </tr>
</table>

<table align="center">
  <tr>
    <td align="center">
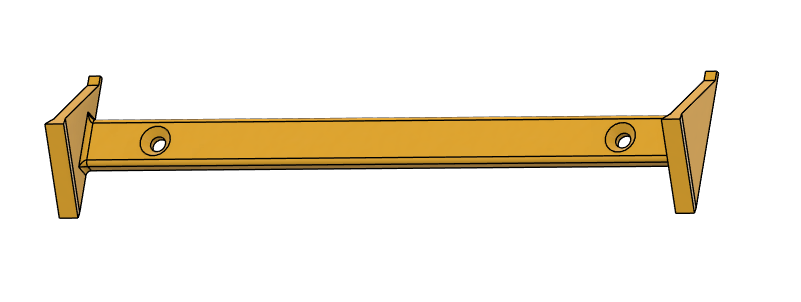
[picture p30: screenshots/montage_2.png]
montage
      <br>
      <sub>Nase Träger</sub>
    </td>
    <td align="center">
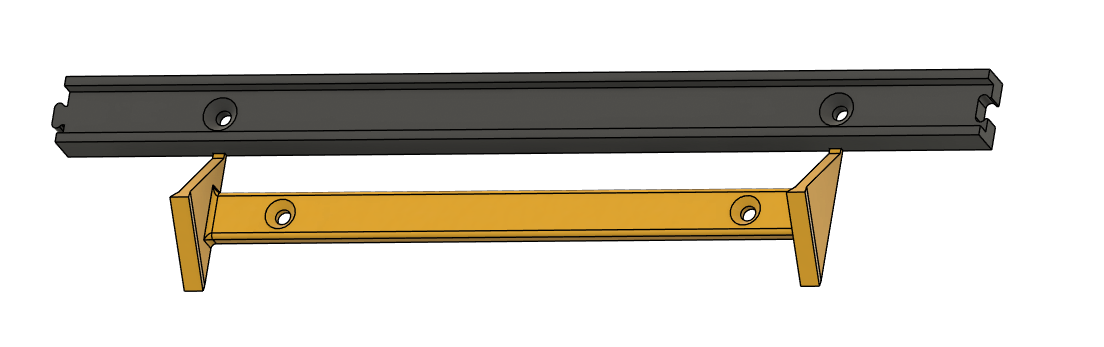
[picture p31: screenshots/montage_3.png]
montage
      <br>
      <sub>ausgerichtet</sub>
    </td>
  </tr>
</table>

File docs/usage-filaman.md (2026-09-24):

# Bedienung bei Anbindung an Filaman

Allgemeine Bedienschritte (WebIF-Übersicht, Home Assistant, Filtern/Sortieren)
stehen in [`usage.md`](usage.md). Hier geht es nur um das, was bei
Anbindung an FilaMan anders läuft als im lokalen Betrieb (siehe
[`usage-local.md`](usage-local.md)).

## NFC-Tags anlegen

1. Im Filaman WebIf die Seite Filamente öffnen.
2. Für jede Farbe, für die man ein Sample anlegen möchte, benötigt das Filament 2 filamentspezifische Extrafelder.

<p align="left">
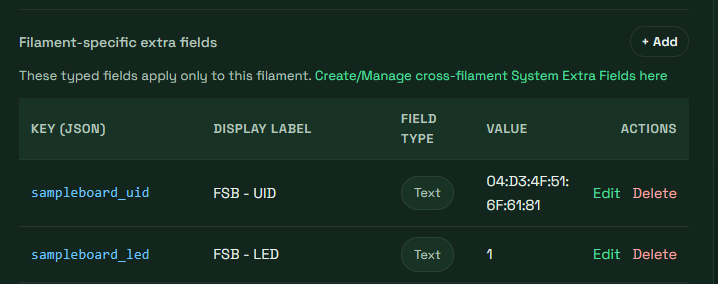
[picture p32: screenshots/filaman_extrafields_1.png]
  
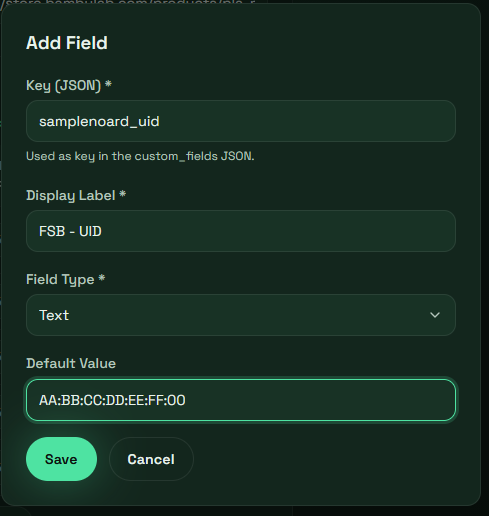
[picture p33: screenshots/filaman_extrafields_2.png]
  
</p>

3. Die Keys **müssen zwingend** `sampleboard_uid` und `sampleboard_led` sein.
4. `sampleboard_uid` bekommt die UID des Sample-NFC-Tags.
5. `sampleboard_led` bekommt die zugeordnete LED auf deinem Board.
6. Im FSB WebIf unter Einstellungen → Filaman die Zugangsdaten eintragen (vorher z. B. einen Nutzer mit nur Leseberechtigung in Filaman anlegen).
7. Im FSB WebIf unter Einstellungen → Sync Filaman ausführen. Das kann je nach DB-Größe (entscheidend ist die Anzahl der Filamente, nicht der Spulen) eine Weile dauern.

## Sample per NFC-Tag finden

NFC-Tag an den Leser halten, FSB zeigt auf dem Display Hersteller, Typ und Farbe aus den eben synchronisierten Daten und fragt zusätzlich bei Filaman den Lagerplatz ab.

Auch im WebIF fragt das FSB nach Auswahl eines Filaments die FilaMan-DB ab und aktualisiert den Lagerort dort live.

## Sample bearbeiten / löschen

Dazu passende UID im Filaman löschen und erneut synchronisieren.

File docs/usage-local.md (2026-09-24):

# Bedienung mit lokaler DB

Allgemeine Bedienschritte (WebIF-Übersicht, Home Assistant, Filtern/Sortieren)
stehen in [`usage.md`](usage.md). Hier geht es nur um das, was beim Betrieb
mit der lokalen `filaments.json` anders läuft als bei der FilaMan-Anbindung
(siehe [`usage-filaman.md`](usage-filaman.md)).

## NFC-Tags anlegen

1. Im WebIf die Seite Settings öffnen
2. NFC-Tag an den Reader halten, der Tag wird automatisch eingetragen
<p align="left">
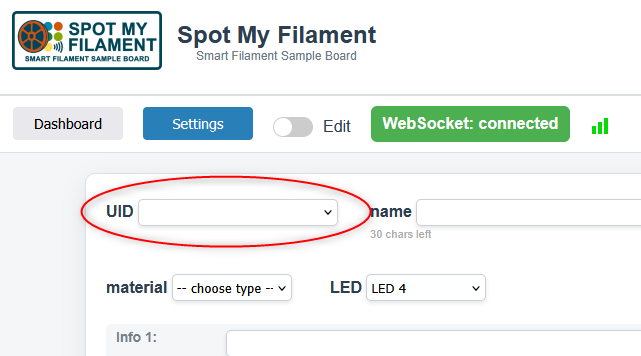
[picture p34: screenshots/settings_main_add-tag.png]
NFC Tag
  
</p>
3. die restlichen Informationen zum Sample eintragen, <b>UID, name, color, material und LED sind Pflichtfelder</b>, der Rest ist optional<br>
4. Es können nur LEDs ausgewählt werden, die noch nicht vergeben sind. Wird eine LED ausgewählt, leuchtet diese entsprechend auf dem Board kurz auf zur Orientierung.<br>
<p align="left">
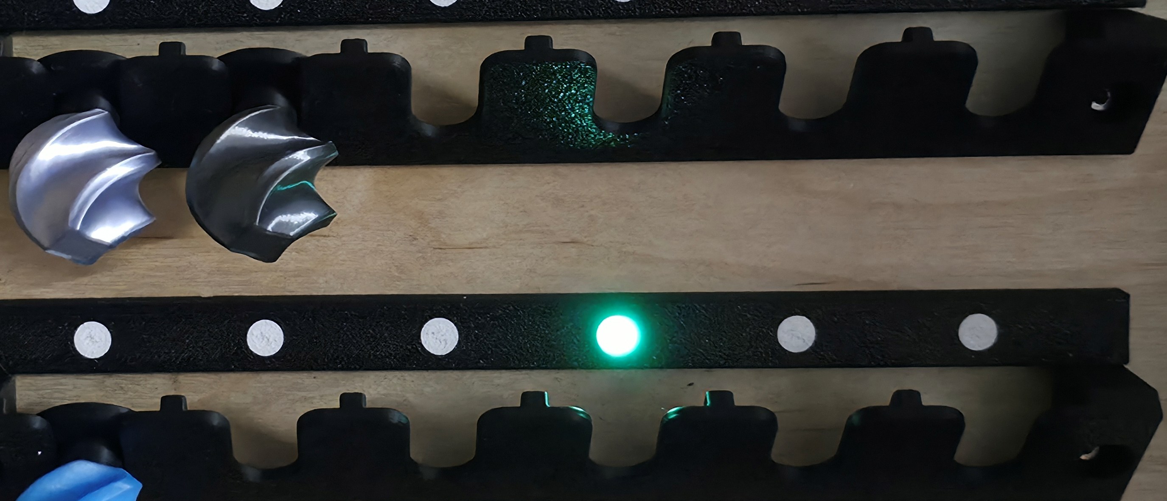
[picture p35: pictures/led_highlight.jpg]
LED highlight
  
</p>

## Sample per NFC-Tag finden

1. NFC-Tag an den Reader halten.
2. Der ESP32 fragt die Datenbank ab und zeigt die Filament-Infos auf dem Display an.
3. Die LED am zugehörigen Sample-Lagerplatz leuchtet auf.
4. Die entsprechende Kachel im WebIF leuchtet auch auf.

## Sample bearbeiten / löschen

Um ein Sample zu bearbeiten oder zu löschen, muss der Schalter "bearbeiten" aktiv sein
<!-- TODO: Ablauf im WebIF genauer beschreiben -->

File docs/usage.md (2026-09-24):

# Bedienung

Diese Seite beschreibt die Bedienschritte, die unabhängig davon gelten, ob
das Board mit der **lokalen DB** oder mit **FilaMan** arbeitet. Details zum
Anlegen und Finden von Samples in den beiden Modi stehen in
[`usage-local.md`](usage-local.md) bzw. [`usage-filaman.md`](usage-filaman.md).

## Sample über das WebIF finden

1. WebIF im Browser öffnen: `http://<ip-des-boards>/`
2. Filament in der Liste auswählen und anklicken.
3. Die passende LED am Board leuchtet auf, um den Sample-Lagerplatz zu markieren.

<p align="center">
  Dashboard mit markiertem Sample
</p>

## Steuerung über Home Assistant

- LEDs und Display lassen sich per Home Assistant ein-/ausschalten. (z.B. schalten per Bewegungssensor)
- Der ESP32 übermittelt den aktuellen Status (z. B. ausgewähltes Filament) an Home Assistant zurück. (z.B. Sprachausgabe)
<!-- TODO: Beispiel-Dashboard-Card / Automatisierung verlinken, falls vorhanden -->

## Sonstiges

<b>Filtern:</b> durch Eingabe von Filterwörtern kann gesucht werden, wird im Material Filter z.B. PLA ausgeählt, leuchten alle PLA Samples.
<b>Sortieren:</b> durch Klick auf den kategorienamen wird auf- bzw. absteigend gefiltert.

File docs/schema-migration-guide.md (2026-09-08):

# Anleitung: Schema-Änderungen an config_v2.json und filaments.json

Diese Anleitung beschreibt, welche Stellen im Code angepasst werden müssen,
wenn ein neues Feld hinzugefügt, ein bestehendes Feld geändert oder entfernt
werden soll — ohne dass bestehende Nutzer ein manuelles LittleFS-Backup/Restore
durchführen müssen.

## Grundprinzip

Firmware-Updates werden nur noch als `firmware.bin` ausgeliefert (OTA über
`update.html`, nur app0/app1-Partition betroffen). Die LittleFS-Partition
(`config_v2.json`, `filaments.json`) bleibt dabei unangetastet. Schema-Änderungen
werden stattdessen beim **Boot** bzw. beim **Web-Import** durch Migrationscode
im Speicher nachgezogen und danach persistiert.

Ein LittleFS-Image (`littlefs.bin`) wird nur noch für die **Erstinstallation**
oder einen bewussten **Factory Reset** verwendet, nie für reguläre Updates.

---

## Teil A: Änderungen an config_v2.json

### A1. Neues Feld hinzufügen (einfacher Skalarwert: bool/int/String)

Checkliste, in dieser Reihenfolge:

1. **`config.h` — Struct erweitern**
   Neues Feld im passenden Sub-Struct ergänzen (`systemConfig`, `LedConfigV2`,
   `NfcLedConfigV2`, `ButtonConfigV2`, `BuzzerConfigV2`, `MqttConfigV2`).

2. **`config.cpp` → `loadConfigV2()` — Auslesen mit Default**
   ```cpp
   CONFIGV2.system.neuesFeld = sys["neuesFeld"] | <sinnvollerDefault>;
   ```
   Der `|`-Default ist dein Sicherheitsnetz gegen alte Dateien ohne dieses Feld —
   er verhindert einen funktionalen Fehler auch ganz ohne Migration.

3. **`config.cpp` → `saveConfigV2()` — Zurückschreiben**
   ```cpp
   system["neuesFeld"] = CONFIGV2.system.neuesFeld;
   ```

4. **`config.cpp` → `updateConfigFromJsonV2()` — Web-UI-Update übernehmen**
   ```cpp
   CONFIGV2.system.neuesFeld = sys["neuesFeld"] | CONFIGV2.system.neuesFeld;
   ```

5. **`config.cpp` → `importConfigJsonV2()` — Web-Import übernehmen**
   Gleiches Pattern wie Punkt 4, im `src["system"]`-Block.

6. **`config.h` → `migrateConfigV2()` — Migrationsschritt ergänzen**
   Nur nötig, wenn der Default aus Punkt 2 *nicht* harmlos ist (siehe A3).
   Für harmlose Defaults reicht der `|`-Fallback aus Punkt 2 — die Migration
   sorgt dann nur dafür, dass der Default auch dauerhaft in die Datei
   geschrieben wird, statt bei jedem Boot neu aus dem Code zu kommen:
   ```cpp
   if (ver == "<alte Version>") {
       if (cfg["system"]["neuesFeld"].isNull()) {
           cfg["system"]["neuesFeld"] = <sinnvollerDefault>;
       }
       Serial.println(F("[MIGRATION] <alt> -> <neu>"));
       ver = "<neu>";
       changed = true;
   }
   ```
   `CURRENT_VERSION`-Konstante in derselben Funktion entsprechend hochzählen.

### A2. Verschachtelte Struktur ändern (z. B. Array → Objekt, Feld umbenannt)

Hier reicht der `|`-Default **nicht** aus, weil sich die Form des Werts ändert,
nicht nur sein Vorhandensein. Beispiel: `"color": [0,255,0]` wird zu
`"color": {"r":0,"g":255,"b":0}`.

Zusätzlich zu A1, Punkt 6 muss der Migrationsschritt das alte Format aktiv
in das neue überführen, **bevor** der normale Auslese-Code läuft:

```cpp
if (ver == "<alte Version>") {
    if (cfg["led"]["color"].is<JsonArray>()) {
        JsonArray old = cfg["led"]["color"];
        JsonObject neu = cfg["led"]["color"].to<JsonObject>(); // überschreibt das Array
        neu["r"] = old[0];
        neu["g"] = old[1];
        neu["b"] = old[2];
    }
    ver = "<neu>";
    changed = true;
}
```

### A3. Wann ein Default *nicht* harmlos ist

Vorsicht bei Feldern, bei denen `0` / `false` / `""` eine gültige, aber
inhaltlich falsche Bedeutung hätte (z. B. `0` bedeutet in der Anwendungslogik
"deaktiviert"). Hier **muss** ein Migrationsschritt (A1, Punkt 6) den echten
Default setzen, sonst verschwindet bei jedem alten Gerät ohne dieses Feld
stillschweigend eine Funktion — ohne Absturz, aber mit stillem Funktionsverlust.

### A4. Feld entfernen

- Auslese-Zeile in `loadConfigV2()` und `importConfigJsonV2()` entfernen.
- Schreib-Zeile in `saveConfigV2()` entfernen.
- Struct-Feld in `config.h` entfernen.
- Kein Migrationsschritt nötig — überzählige Felder in alten Dateien werden
  beim nächsten `saveConfigV2()` automatisch nicht mehr mitgeschrieben.

---

## Teil B: Änderungen an filaments.json

Die Filament-DB ist ein Array ohne eigenes `version`-Feld. Migrationen werden
daher über `CONFIGV2.system.version` gesteuert (an dieser Stelle bereits durch
`loadConfigV2()` migriert und gesetzt, bevor `loadFilaments()` läuft).

### B1. Neues Feld hinzufügen

1. **`filament_db.h` → `FilamentEntry`-Struct erweitern**
   ```cpp
   String neuesFeld;
   ```

2. **`filament_db.cpp` → `loadFromJsonArray()` — Lesen mit Default**
   ```cpp
   db[dbCount].neuesFeld = o["neuesFeld"] | "";
   ```

3. **`filament_db.cpp` → `toJsonArray()` — Zurückschreiben**
   ```cpp
   o["neuesFeld"] = db[i].neuesFeld;
   ```

4. **`filehandling.h` → `migrateFilamentEntry()` — nur bei nicht-harmlosem Default**
   ```cpp
   if (configVersion == "<alte Version>") {
       if (entry["neuesFeld"].isNull()) {
           entry["neuesFeld"] = <sinnvollerDefault>;
           changed = true;
       }
   }
   ```

### B2. Feld entfernen

Analog zu A4: Zeilen in `loadFromJsonArray()`, `toJsonArray()` und das
Struct-Feld entfernen. Kein Migrationsschritt nötig.

---

## Teil C: Zwei Aufrufpfade — beide müssen migriert werden

Jede Schema-Änderung existiert in **zwei** Pfaden, die unabhängig voneinander
laufen. Ein Fix nur in einem Pfad reicht nicht:

| Pfad | Config | Filamente |
|---|---|---|
| Boot | `loadConfigV2()` | `loadFilaments()` |
| Web-Import | `importConfigJsonV2()` | `importFilamentsJson()` |

**Beispiel aus der Praxis:** `migrateConfigV2()` wurde korrekt im Import-Pfad
aufgerufen, aber der migrierte `version`-Wert wurde dort nicht nach
`CONFIGV2.system.version` übertragen. `saveConfigV2()` liest beim Schreiben
aber aus `CONFIGV2`, nicht aus dem migrierten JSON — dadurch wurde die
Migration beim Speichern wieder überschrieben. Lehre daraus: Bei jeder neuen
Migration prüfen, ob **alle** Stellen, die den Wert lesen, schreiben oder
weiterreichen, den aktuellen (migrierten) Stand tatsächlich verwenden.

---

## Teil D: Checkliste zum Abhaken

Bei jeder neuen Schema-Version:

- [ ] Struct in `config.h` bzw. `filament_db.h` erweitert/angepasst
- [ ] Lesen mit Default in `loadConfigV2()` bzw. `loadFromJsonArray()`
- [ ] Schreiben in `saveConfigV2()` bzw. `toJsonArray()`
- [ ] Web-UI-Update-Pfad (`updateConfigFromJsonV2()`) berücksichtigt
- [ ] Web-Import-Pfad (`importConfigJsonV2()` / `importFilamentsJson()`) berücksichtigt
- [ ] Bei nicht-harmlosem Default: Migrationsschritt in `migrateConfigV2()` /
      `migrateFilamentEntry()` ergänzt
- [ ] `CURRENT_VERSION`-Konstante in `migrateConfigV2()` hochgezählt
- [ ] Mit Testdatei (alte Version, per Web-Import UND per Boot) verifiziert,
      dass die neue Version tatsächlich persistiert wird
- [ ] Alten Migrationsschritt **nicht** nachträglich verändert — neue Stufe
      stattdessen als zusätzlichen Block anhängen

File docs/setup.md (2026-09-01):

# Setup & Konfiguration

Diese Anleitung beschreibt, wie die Firmware aufgespielt und das Board eingerichtet wird.

## Installation
### 1. Möglichkeit: Webinstaller
[webinstaller](https://mark77-de.github.io/Smart-Filament-Sample-Board/webinstaller/)
Dort auswählen, welches Display man nutzen möchte.
Aktuell SSD1306 OLED, SH1106 OLED oder ST7789 TFT.<br>
Details unter [hardware](./hardware.md)

### 2. Möglichket: .bin herunterladen und flashen
Diese liegen hier: [Releases](https://github.com/mark77-DE/Smart-Filament-Sample-Board/releases)

### 3. Möglichkeit: Repo clonen und selbst kompilieren und flashen

## Setup (nur die Basics)
### 1. Start
Beim ersten Start wird nachden WLAN-Setting gefragt, dazu öffnet der ESP einen Hotspot mit der SSID "SpotMyFilament".
Hier verbinden und die IP Adresse 192.168.4.1 im Browser eintragen und die eigenen WLAN-Daten eintragen und speichern.

### 2. LEDs konfigurieren
Hier sollte die Anzahl der LEDs konfiguriert werden. Diese sollte der Anzahl der Plätze für Samples entsprechen.
<p align="center">
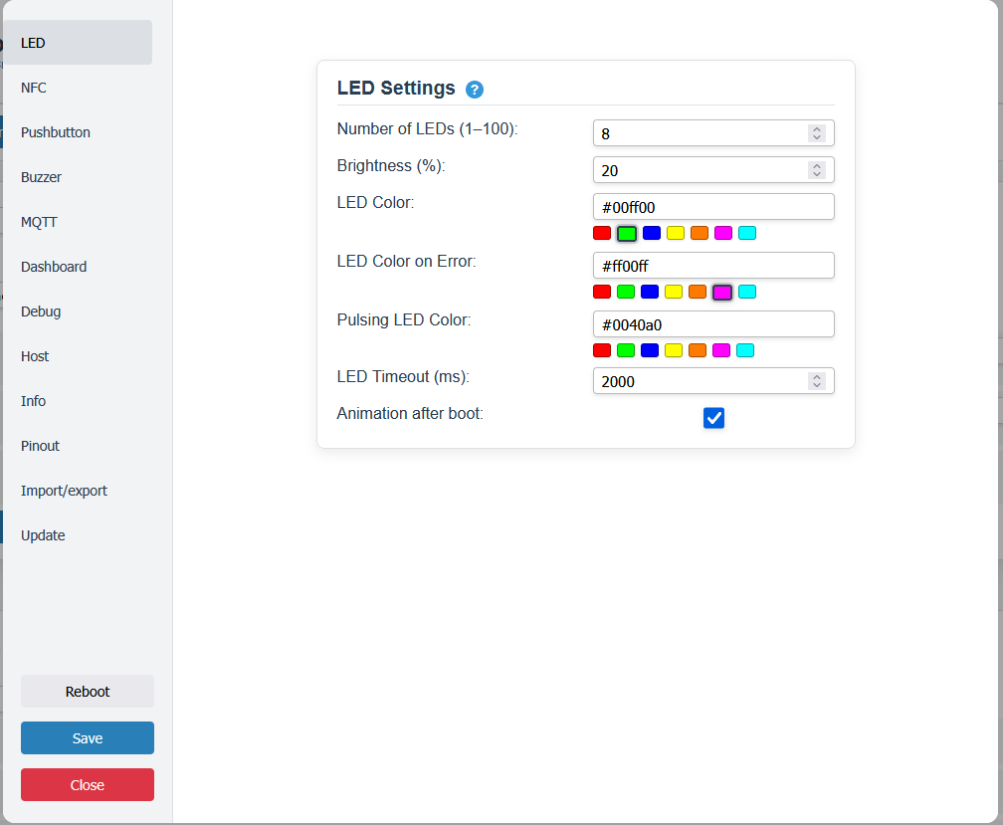
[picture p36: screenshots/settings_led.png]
settings LED
  <br>
  <sub>LEDs konfigurieren</sub>
</p>

### 3. NFC-LEDs konfigurieren
Hier sollte die Anzahl der LEDs 12 bleiben, wenn die 3D-Druckteile aus dem Repo benutz werden.
<p align="center">
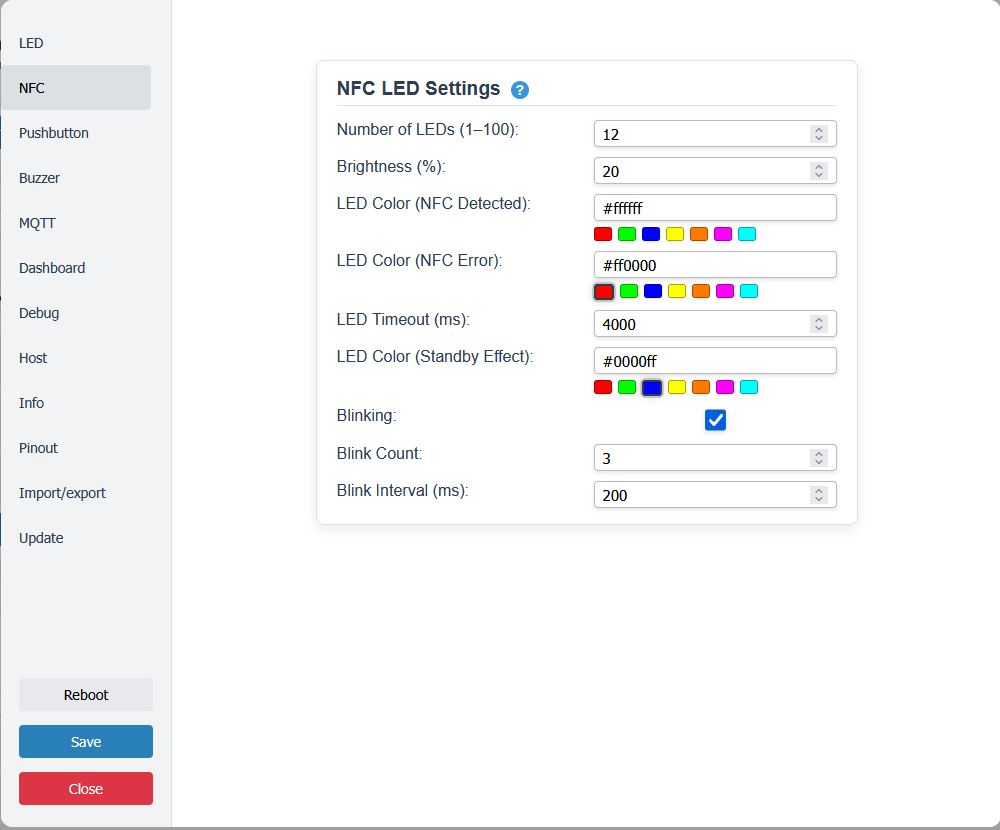
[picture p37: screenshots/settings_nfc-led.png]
settings NFC-LED
  <br>
  <sub>NFC-LEDs konfigurieren</sub>
</p>

### 4. optional MQTT konfigurieren
<p align="center">
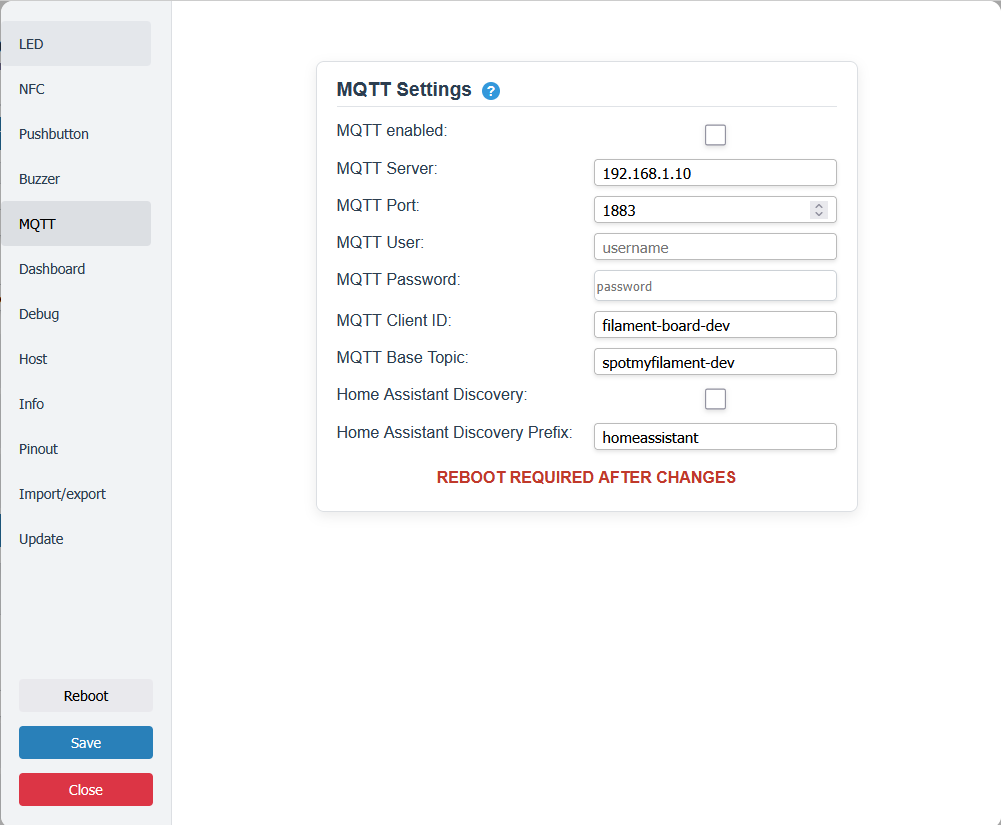
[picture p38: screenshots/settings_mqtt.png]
settings NFC-LED
  <br>
  <sub>MQTT konfigurieren</sub>
</p>
<b>Werden hier Einstellungen gemacht, muss ein Neustart erfolgen</b>

## Troubleshooting
<p align="center">
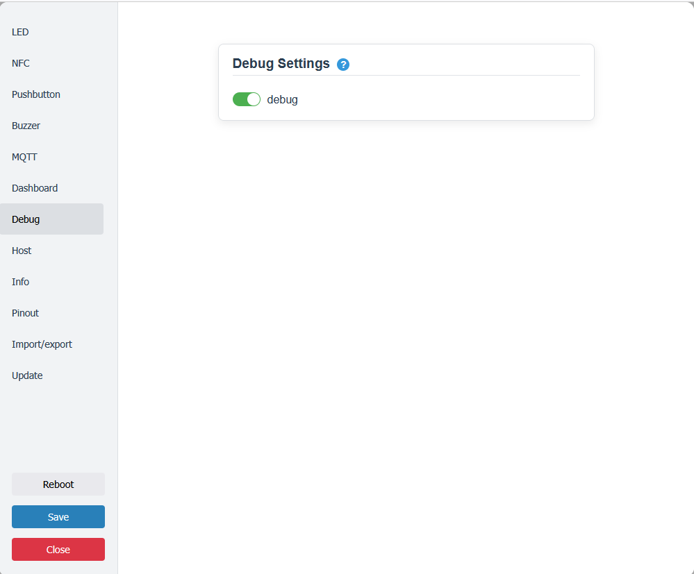
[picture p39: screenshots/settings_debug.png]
settings debug
  <br>
  <sub>Debug (de)aktivieren</sub>
</p>
Ausgabe der Debug Daten über die serielle Schnittstelle.

<!-- TODO: häufige Probleme, z. B.
- NFC-Reader wird nicht erkannt → Verkabelung/Adresse prüfen
- Keine MQTT-Verbindung → Broker-IP/Zugangsdaten prüfen
-->

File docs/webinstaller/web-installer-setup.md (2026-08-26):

# Web-Installer einrichten (GitHub Pages)

Diese Anleitung beschreibt, wie der browserbasierte Firmware-Installer
(`webinstaller/index.html`) live geschaltet wird — genau das Prinzip, das auch
WLED oder FilaMan nutzen ([ESP Web Tools](https://esphome.github.io/esp-web-tools/)).

## Funktionsprinzip

Die Seite nutzt die **Web Serial API** des Browsers, um sich direkt per USB mit
dem ESP32 zu verbinden. Ein `<esp-web-install-button>`-Element liest ein
`manifest.json`, das beschreibt, welche Firmware-Dateien es gibt und an welche
Flash-Adressen sie geschrieben werden. Kein Server-Backend nötig — alles läuft
im Browser.

**Voraussetzung:** Die Seite muss über **HTTPS** ausgeliefert werden (Sicherheitsanforderung
von Web Serial). GitHub Pages erfüllt das automatisch.

## 1. Firmware-Binärdateien exportieren

Aus der Arduino IDE:

1. Sketch kompilieren: **Sketch → Kompilieren** (nicht hochladen).
2. **Sketch → Kompilierten Sketch exportieren** — legt die `.bin`-Dateien im Sketch-Ordner ab.
3. Folgende Dateien werden benötigt (Namen können je nach Board-Package leicht abweichen):
   - `<sketchname>.ino.bootloader.bin` → als `bootloader.bin`
   - `<sketchname>.ino.partitions.bin` → als `partitions.bin`
   - `boot_app0.bin` (liegt im ESP32-Board-Package, z. B. unter
     `~/Arduino/hardware/espressif/esp32/tools/partitions/`)
   - `<sketchname>.ino.bin` → als `firmware.bin`
4. Alle vier Dateien in `webinstaller/firmware/` ablegen (Namen exakt wie im
   `manifest.json` erwartet, siehe unten).

**Bei PlatformIO:** liegen die Dateien nach `pio run` unter `.pio/build/<env>/`.

## 2. manifest.json prüfen/anpassen

```json
{
  "name": "Smart Filament Sample Board",
  "version": "1.0.0",
  "builds": [
    {
      "chipFamily": "ESP32",
      "parts": [
        { "path": "firmware/bootloader.bin", "offset": 4096 },
        { "path": "firmware/partitions.bin", "offset": 32768 },
        { "path": "firmware/boot_app0.bin", "offset": 57344 },
        { "path": "firmware/firmware.bin", "offset": 65536 }
      ]
    }
  ]
}
```

- `version` bei jedem Release hochzählen.
- Falls du zusätzlich eine ESP32-S3-Variante unterstützt: einen weiteren
  Eintrag im `builds`-Array mit `"chipFamily": "ESP32-S3"` ergänzen (eigener
  Satz Binärdateien nötig, meist ab Offset `0` statt `4096`).
- `home_assistant_domain` ist optional, hilft aber, wenn das Board per
  ESPHome/Discovery erkannt werden soll.

## 3. GitHub Pages aktivieren

1. Im Repo: **Settings → Pages**.
2. Unter **Build and deployment → Source**: `Deploy from a branch` wählen.
3. **Branch**: `main`, Ordner: `/docs` <!-- TODO: an tatsächliche Ordnerstruktur anpassen, falls webinstaller nicht unter docs/ liegt -->.
4. Speichern — nach ein bis zwei Minuten ist die Seite erreichbar unter:

   ```
   https://mark77-de.github.io/Smart-Filament-Sample-Board/webinstaller/
   ```

5. Falls die Markdown-Dateien in `docs/` dabei ungewollt als Jekyll-Seite
   gerendert werden: eine leere Datei `docs/.nojekyll` anlegen, dann liefert
   GitHub Pages alle Dateien unverändert aus.

## 4. Testen

1. Installer-URL in Chrome, Edge oder Firefox öffnen (nicht Safari/iOS).
2. ESP32 per USB-**Datenkabel** anschließen.
3. „Verbinden & installieren" klicken, Port bestätigen.
4. Flash-Vorgang abwarten — das Board startet danach neu.

## 5. Bei jedem neuen Firmware-Release

1. Neue `.bin`-Dateien exportieren (Schritt 1).
2. Alte Dateien in `webinstaller/firmware/` überschreiben.
3. `version` in `manifest.json` hochzählen.
4. Änderungen committen und pushen — GitHub Pages aktualisiert sich automatisch.

<!-- TODO: Optional, wenn das nervt: einen GitHub-Actions-Workflow einrichten,
der bei jedem Tag/Release automatisch kompiliert, die .bin-Dateien exportiert
und das Manifest aktualisiert. Sag Bescheid, wenn du dabei Hilfe möchtest. -->

## Troubleshooting

| Problem | Lösung |
|---|---|
| Button zeigt „Browser wird nicht unterstützt" | Chrome, Edge oder Firefox auf dem Desktop verwenden, nicht Safari/iOS |
| Verbindung bricht ab / Bootloop nach dem Flashen | Bei ESP-IDF v4+/neueren Arduino-Cores ggf. Binärdateien vorher mit `esptool.py merge_bin` zusammenführen |
| 404 beim Laden von `manifest.json` | Pfade in `manifest.json` sind relativ zur `index.html` — Ordnerstruktur prüfen |
| CORS-Fehler | Nur relevant, falls Manifest/Firmware auf einem anderen Host liegen als die Seite selbst |

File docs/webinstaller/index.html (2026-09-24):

Firmware Installer

Smart Filament Sample Board Logo

# Smart Filament Sample Board

Firmware direkt aus dem Browser aufspielen — kein Arduino IDE, keine Kommandozeile nötig.

SH1106 OLED ST7789 TFT

Ausgewählt: SH1106 OLED

## Board verbinden & flashen

ESP32 per USB anschließen, dann auf Verbinden klicken.
Der Chip-Typ (ESP32 / ESP32-S3) wird automatisch erkannt.

Verbinden & installieren Dein Browser unterstützt Web Serial nicht. Bitte Chrome, Edge oder Firefox auf dem Desktop verwenden. Diese Seite muss über HTTPS aufgerufen werden, damit das Flashen funktioniert.

Chrome / Edge / Firefox USB-Kabel mit Datenleitung Nicht auf iOS

1. Display-Variante oben auswählen — je nachdem, welches Display auf deinem Board verbaut ist.
2. Board per USB anschließen — ein Datenkabel verwenden, kein reines Ladekabel.
3. Verbinden & installieren klicken und den seriellen Port in der Browser-Auswahl bestätigen.
4. Warten, bis der Flash-Vorgang abgeschlossen ist — das Board startet danach automatisch neu.

Zum Repository (https://github.com/mark77-DE/Smart-Filament-Sample-Board) · Dokumentation

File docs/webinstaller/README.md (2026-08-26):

# firmware/

Hier liegen die kompilierten Binärdateien, auf die `manifest.json` verweist.

Diese Dateien werden hier NICHT mitgeliefert - sie müssen bei jedem Release
neu exportiert und hier abgelegt (bzw. per GitHub Release-Workflow erzeugt) werden:

- bootloader.bin
- partitions.bin
- boot_app0.bin
- firmware.bin

Siehe `docs/web-installer-setup.md` für die genaue Anleitung zum Export
aus der Arduino IDE.

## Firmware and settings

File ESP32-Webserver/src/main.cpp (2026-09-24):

#include <WiFi.h>
#include <WiFiManager.h>
#include <ESPAsyncWebServer.h>
#include <Wire.h>
#include <SPI.h>
#include <Adafruit_PN532.h>
#include <ArduinoJson.h>
#include <LittleFS.h>
#include "filament_db.h"
#include "ledctrl_filament.h"
#include "ledctrl_nfc.h"
#include "display/display.h"
#include "display/display_config.h"
#include "display/display_anim.h"
#include "display/st7789/display_st7789.h"
#include "my_webserver.h"
#include "globals.h"

#include "nfc.h"
#include "filehandling.h"
#include "gpio_hardware.h"
#include "version_info.h"
#include "reboot_handler.h"
#include "pins.h"
#include "Arduino.h"
#include "esp_ota_ops.h"
#include "config.h"
#include "mqtt_manager.h"
#include "i18n/i18n.h"
#include <HTTPClient.h>
#include <WiFiClientSecure.h>
#include "update_manager.h"
#include "time_manager.h"

#include "filaman_manager.h"
#include "filaman_sync_apply.h"

#include <esp_heap_caps.h>

#include <vector>

#include "debug_utils.h"

constexpr uint32_t SPLASH_CHAR_MS = 35;   // timing for typewriter effect at boot (ms per char)
constexpr uint32_t SPLASH_LINE_MS = 200;  // extra delay after each line at boot (ms)
constexpr uint32_t SPLASH_HOLD_MS = 2000; // how long the full splash is shown at boot (after typewriter effect, before animation starts)

constexpr uint32_t FIRMWARE_HOLD_MS = 2000; // how long fw version is shown at boot (before animation starts)

SysInfo g_sysInfo;

NFCInfo g_nfcInfo = {0, 0, 0, false};

bool rebootReason = false;

static String g_lastHandledUid;
static UidSource g_lastHandledSource = UidSource::NFC;

volatile bool factoryResetRequested = false;

static void printOtaInfo()
{
  const esp_partition_t *boot = esp_ota_get_boot_partition();
  const esp_partition_t *run = esp_ota_get_running_partition();

  DEBUG_BLOCK(Serial.println());

  DEBUG_LOGF("OTA", "boot: name=%s addr=0x%06X subtype=0x%02X",
             boot ? boot->label : "null",
             boot ? (unsigned)boot->address : 0,
             boot ? (unsigned)boot->subtype : 0);

  DEBUG_LOGF("OTA", "run : name=%s addr=0x%06X subtype=0x%02X",
             run ? run->label : "null",
             run ? (unsigned)run->address : 0,
             run ? (unsigned)run->subtype : 0);

  if (run)
  {
    esp_ota_img_states_t st{};
    if (esp_ota_get_state_partition(run, &st) == ESP_OK)
    {
      DEBUG_LOGF("OTA", "state: %d (PENDING_VERIFY=%d)",
           (int)st, (int)ESP_OTA_IMG_PENDING_VERIFY);
      
    }
  }
}

static void markOtaImageValidIfNeeded()
{
  const esp_partition_t *running = esp_ota_get_running_partition();
  if (!running)
    return;

  esp_ota_img_states_t state{};
  if (esp_ota_get_state_partition(running, &state) != ESP_OK)
    return;

  if (state == ESP_OTA_IMG_PENDING_VERIFY)
  {
    Serial.println("OTA: marking app valid (cancel rollback)...");
    esp_ota_mark_app_valid_cancel_rollback();
  }
}

// ----------------- Server & WS -----------------
AsyncWebServer server(80);
AsyncWebSocket ws("/ws");

// ----------------- OLED ---------------

// ----------------- PN532 SPI Settings -----------------
Adafruit_PN532 nfc(NFC_SPI_SCK, NFC_SPI_MISO, NFC_SPI_MOSI, NFC_SPI_CS);

// ----------------- LED & Display Timing -----------------
int targetLed = -1;
unsigned long ledStartTime = 0;
unsigned long lastTagTime = 0;
unsigned long now = 0;
bool isActive = false;

// ----------------- global variables -----------------
String activeUID = ""; // active UID

volatile bool g_applyConfigPending = false;
volatile bool g_reloadFilamentsPending = false;

// global WebIF timer variables + setters

static bool s_webifIdleArmed = false;
static uint32_t s_webifIdleUntil = 0;

void webifArmIdleTimeout(uint32_t ms)
{
  if (ms == 0)
    ms = 1;
  s_webifIdleArmed = true;
  s_webifIdleUntil = millis() + ms;
}

bool webifIsArmed()
{
  return s_webifIdleArmed;
}

void webifCancelIdleTimeout()
{
  s_webifIdleArmed = false;
}

bool webifIdleDue(uint32_t now)
{
  if (!s_webifIdleArmed)
    return false;
  return (int32_t)(now - s_webifIdleUntil) >= 0;
}

// ----------------- Hilfsfunktionen -----------------

// WiFiManager: wird aufgerufen, sobald das Config-Portal/AP gestartet ist.
// Purpose: when the ESP is new and not yet connected to the router, show the AP IP immediately
// so the user knows where to connect (typically: http://192.168.4.1).
// NEW: Also show the SSID on the second line.
static void onWiFiManagerConfigPortalStarted(WiFiManager *wm)
{
  (void)wm;
  const IPAddress apIp = WiFi.softAPIP();
  Serial.printf("WiFiManager AP started. AP IP: %s\n", apIp.toString().c_str());

  // Do NOT block display updates: autoConnect() continues; the display remains until the next change.
  MYDISPLAY::showThreeLinesCentered(
      F("WLAN-SETUP AP"),
      F("SSID: SpotMyFilament"), // SpotMyFilament AP
      apIp.toString(), TFT_ORANGE);
}

// Reboot
void renderRebootCountdown(unsigned long nowMs)
{
  static bool inReboot = false;
  static uint32_t lastSec = 0xFFFFFFFF;

  if (!rebootPending)
  {
    if (inReboot)
    {
      inReboot = false;

      // Release presence and reset cleanly so the next start begins from zero
      LEDCTRL_NFC::tagPresenceTick(false);
      LEDCTRL_FILAMENT::tagPresenceTick(false);
      LEDCTRL_NFC::allOff();
      LEDCTRL_FILAMENT::allOff();

      lastSec = 0xFFFFFFFF;
    }
    return;
  }

  // --- Reboot active ---
  if (!inReboot)
  {
    inReboot = true;
    lastSec = 0xFFFFFFFF;

    if (rebootReason)
    {
      LEDCTRL_NFC::showSuccess();       // NFC ring immediately green (solid)
      LEDCTRL_FILAMENT::successBlink(); // Filament: blinks -> green (
      DEBUG_LOG("System", "Reboot countdown: SUCCESS");
      
    }
    else
    {
      // On countdown start, always switch to error once (single-time)
      LEDCTRL_NFC::showError();       // NFC-Ring sofort rot (solid)
      LEDCTRL_FILAMENT::errorBlink(); // Filament: blinks -> red (as intended)
      DEBUG_LOG("System", "Reboot countdown: ERROR or user reboot");
      
    }
  }

  // Hold presence so solid/error does not time out
  LEDCTRL_NFC::tagPresenceTick(true);
  LEDCTRL_FILAMENT::tagPresenceTick(true);

  // Countdown-Text nur bei Sekundenwechsel neu zeichnen
  const uint32_t remainingMs = (nowMs < rebootAt) ? (rebootAt - nowMs) : 0;
  const uint32_t sec = (remainingMs + 999U) / 1000U;
  if (sec != lastSec)
  {
    lastSec = sec;
    char line2[24];
    snprintf(line2, sizeof(line2), "%lu s", (unsigned long)sec);
    MYDISPLAY::showThreeLinesCentered(
        F("Reboot in :"),
        String(line2),
        F("Press to Cancel"));
  }
}

void activateLed(int index)
{

  DEBUG_LOGF("led", "activateLed: index=%i", index);

  if (targetLed != -1 && targetLed != index)
  {
    LEDCTRL_FILAMENT::setPixel(targetLed, 0); // alte LED aus
  }

  if (index >= 0 && index < LED_COUNT)
  {
    LEDCTRL_FILAMENT::setPixel(index, LED_COLOR);
    targetLed = index;
    ledStartTime = millis();
  }
  else
  {
    targetLed = -1;
  }
}

void handleUID(const String &uid, UidSource source)
{
  lastTagTime = millis();
  isActive = true;
  g_lastHandledUid = uid;
  g_lastHandledSource = source;
  DisplayAnim::stop();

  FilamentEntry entry;
  JsonDocument doc;
  doc["uid"] = uid;

  
  DEBUG_LOGF("uid", "handleUID: UID=%s, Source=%s", uid.c_str(), (source == UidSource::NFC) ? "NFC" : "WebIF");

  const bool isNfc = (source == UidSource::NFC);

  if (FilamentDB::findByUID(uid, entry))
  {
    // --- BEKANNTES TAG (lokal synchronisiert) ---
    activateLed(entry.ledIndex);

    // Sofort mit dem lokal bekannten (ggf. etwas veralteten) Lagerort anzeigen
    MYDISPLAY::showFourLinesCentered(entry.vendor, entry.type, entry.color, entry.storage);

    if (CONFIGV2.mqttConfig.enabled)
    {
      publishFilamentState(entry);
    }

    if (isNfc)
    {
      LEDCTRL_NFC::showSuccess();
    }

    if (isNfc && !buzzer_busy())
    {
      buzzer_single_beep();
    }

    doc["action"] = "knownUID";
    doc["ledIndex"] = entry.ledIndex;
    doc["vendor"] = entry.vendor;
    doc["type"] = entry.type;
    doc["color"] = entry.color;

    // Lagerort im Hintergrund live nachladen — bewusst OHNE "Suche..."
    // Zwischenbildschirm, da Identität schon feststeht und angezeigt ist;
    // nur der (potenziell veraltete) Lagerort wird per loop()-Poll ersetzt.
    if (CONFIGV2.filamanConfig.enabled && entry.filamentId >= 0)
    {
      if (FilamanManager::requestLocationLookup(entry.filamentId, uid) && CONFIGV2.system.debugMode)
      {
        Serial.println("[FILAMAN] request live location");
      }
    }
  }
  else
  {
    // --- UNBEKANNTES TAG ---
    // Kein Live-Fallback mehr möglich: sampleboard_uid/_led sitzen nur noch
    // am Filament in FilaMan, nicht mehr an einer Spule. Ein wirklich
    // unbekanntes Tag wird erst nach dem nächsten FilaMan-Sync auflösbar.

    if (CONFIGV2.system.debugMode)
    {
      Serial.println("[NFC] tag unbekannt");
    }

    if (targetLed != -1)
    {
      LEDCTRL_FILAMENT::setPixel(targetLed, 0);
      targetLed = -1;
      ledStartTime = millis();
    }

    MYDISPLAY::showErrorCentered(I18N::get("txt_unknown"), TFT_RED);

    if (isNfc)
    {
      LEDCTRL_NFC::showError();
      LEDCTRL_FILAMENT::errorBlink();
    }

    doc["action"] = "unknownUID";
  }

  String msg;
  serializeJson(doc, msg);
  ws.textAll(msg);
}

void printChipInfo()
{

  Serial.printf("ESP-Typ: %s\n", g_sysInfo.chipName);
  Serial.printf("Cores: %d\n", g_sysInfo.cores);
  Serial.printf("Rev: %d\n", g_sysInfo.revision);
  Serial.printf("Flash Size: %lu bytes\n", g_sysInfo.flashSize);
  Serial.printf("Board Variant: %s\n", BOARD_VARIANT);
  Serial.println();
  Serial.println();
}

void resetWiFiSettings()
{
  WiFiManager wifiManager;

  Serial.println("[FACTORY RESET] Resetting WiFi settings...");

  wifiManager.resetSettings();
}

void factoryReset()
{
  Serial.println("[FACTORY RESET] Starting...");

  // Delete WiFiManager credentials
  resetWiFiSettings();

  // Reset filaments,jso to default
  resetFilamentsToDefaults();

  // Reset application configuration to defaults
  resetConfigToDefaults();

  // Save default configuration
  saveConfigV2();

  Serial.println("[FACTORY RESET] Restarting...");

  delay(500);
  ESP.restart();
}

// ----------------------------- Setup -----------------------------
// -----------------------------------------------------------------
void setup()
{
  rebootReason = false;
  Serial.begin(115200);
  delay(5000);

  Serial.println();
  Serial.println();
  Serial.println("++-------------------------------++");
  Serial.println("++  SMART FILAMENT SAMPLE BOARD  ++");
  Serial.println("++-------------------------------++");
  Serial.println();
  Serial.println("Booting...");

  printOtaInfo();

  markOtaImageValidIfNeeded();

  Serial.println();
  Serial.printf("FW version: %s\n", FIRMWARE_VERSION);
  Serial.printf("Build date: %s\n", BUILD_DATE);
  Serial.println();

  g_sysInfo = getSysInfo();

  DEBUG_BLOCK(printChipInfo());

  loadConfigV2();

  applyConfigV2();

  I18N::begin(CONFIGV2.system.defaultLanguage);

  LEDCTRL_FILAMENT::allOff();
  LEDCTRL_NFC::allOff();

  // 2) initialize I2C + DISPLAY
  // SPI.begin(SPI_SCK, SPI_MISO, SPI_MOSI);
  displayInit();

  // 3) WLAN verbinden
  //    Desired behavior:
  //    - If it is NOT connected and WiFiManager starts the AP config portal:
  //      -> Show the AP IP immediately (callback), so the user knows where to connect.
  //    - Only once it is connected to the router:
  //      -> Show "CONNECTING..." and then the router IP.
  WiFiManager wifiManager;
  wifiManager.setDebugOutput(CONFIGV2.system.debugMode);

  wifiManager.setAPCallback(onWiFiManagerConfigPortalStarted);

  if (CONFIGV2.system.hostname.length() > 0)
  {
    WiFi.setHostname(CONFIGV2.system.hostname.c_str()); // <- hier
    Serial.printf("[Hostname]: %s\n", CONFIGV2.system.hostname.c_str());
  }

  // Optional: neutral display while autoConnect() decides (router vs. AP portal).
  // If the AP starts, the callback automatically overrides this display.
  MYDISPLAY::showCentered("WLAN...");

  if (!wifiManager.autoConnect("SpotMyFilament"))
  {
    ESP.restart();
  }

  // From here on: router connected
  MYDISPLAY::showCentered("VERBINDUNG...");

  Serial.printf("IP-Address:  %s\n", WiFi.localIP().toString().c_str());
  String mac = WiFi.macAddress();
  Serial.printf("MAC-Address: %s\n", mac.c_str());
  Serial.println();

  // 4) Show the IP briefly (do not block hard)
  {
    MYDISPLAY::showCentered(WiFi.localIP().toString(), TFT_GREEN);
    const uint32_t until = millis() + 1200UL;
    while ((int32_t)(until - millis()) > 0)
    {
      gpiohw_tick(millis()); // Button/Buzzer am Leben halten
      yield();
    }
  }

  // init network time
  TimeManager::init();

  // init MQTT
  if (CONFIGV2.mqttConfig.enabled)
  {
    Serial.println("[MQTT] enabled i config, initializing...");

    if (WiFi.status() == WL_CONNECTED)
    {
      mqttInit();
    }
  }
  else
  {
    DEBUG_LOG("MQTT", "disabled in config, skipping initialization.");
  }

  // Upadte Check

  updateInit();
  updateLoop(); // initial einmal

  MYDISPLAY::showBootVersion(FIRMWARE_VERSION, BUILD_DATE_SHORT);

  const uint32_t until = millis() + FIRMWARE_HOLD_MS;
  while ((int32_t)(until - millis()) > 0)
  {
    gpiohw_tick(millis());
    ws.cleanupClients();
    yield();
  }

  // After the firmware boot screen (10 s), WLAN + web server are already active
  displayClear();
  DisplayAnim::playThreeLineTypewriter(display, F("Spot my"), F("Filament by"), F("Mark & Kolja"),
                                       SPLASH_CHAR_MS, SPLASH_LINE_MS, SPLASH_HOLD_MS);

  // 7) Initialize PN532 now (can write to the display in case of errors)
  uint32_t version = NFC::init(&nfc); // begin() + SAMConfig(), FW wird intern geloggt

  if (!version)
  {
    MYDISPLAY::showCentered("PN532 FEHLER!");
    g_nfcInfo.available = false;
    // while (1) { delay(100); }
  }
  else
  {
    g_nfcInfo.available = true;
    g_nfcInfo.fwVerMajor = (version >> 24) & 0xFF;
    g_nfcInfo.fwVerMinor = (version >> 16) & 0xFF;
    g_nfcInfo.chipID = version & 0xFFFF;
  }

  // 8) Idle-Animation vorbereiten
  DisplayAnim::startIdleTextFirst(millis());

  // 5) Start WebSocket + web server (WebIF is immediately reachable now)
  // FIX: avoid duplicate WS registration - add it only in the web server module
  // server.addHandler(&ws); // <-- ENTFERNT, Registrierung erfolgt in initWebServer()
  initWebServer(server, ws);
  WiFi.setSleep(false);

  // Only once, no duplicate call:
  if (WiFi.status() == WL_CONNECTED)
  {
    FilamanManager::requestWarmup(); // Session + location cache first

    // Automatic boot sync only if this is really desired (see the follow-up question) —
    // otherwise omit it here and trigger only via button/WebIF.
    // FilamanManager::requestSync();
  }
  else if (CONFIGV2.system.debugMode)
  {
    Serial.println("[FILAMAN] boot: WiFi not yet connected, skipping warmup/sync");
  }

  Serial.println();
  Serial.println();
  Serial.println("*****************************************");
  Serial.println("*  Setup complete, enjoy your samples!  *");
  Serial.println("*****************************************");
  Serial.println();
  Serial.println();
}
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

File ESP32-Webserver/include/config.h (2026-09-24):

#pragma once
#include <Arduino.h>
#include <ArduinoJson.h>

#include "led_config.h"

// OPTIONAL: Marker so gpio_hardware.cpp knows that
// Button/buzzer are present in CONFIG:
#define CONFIG_HAS_GPIO


// ============================================================================
// Configuration structures
// ============================================================================
/**
 * @brief System
 * Configuration
 */

struct systemConfig {
  String        version               = "error";      
  bool          darkmode              = false;                      ///< Dark mode enabled
  bool          debugMode             = true;                       ///< Debug mode enabled
  uint32_t      webLEDTimeout         = 3000;                       ///< Dashboard default (ms)
  String        hostname              = "filament-sample-board";    ///< Wi-Fi hostname
  bool          animationAfterBoot    = true;                       ///< Startup animation after boot enabled
  String        defaultLanguage       = "en";                       ///< Default language (e.g. "en" or "de")
  uint32_t      updateCheckInterval   = 240;                        ///< Seconds until reboot after long press
  String        timezone              = "UTC";                      // POSIX-TZ-String, example see TIMEZONE in platformio.ini
};



/**
 * @brief Global LED hardware configuration
 *
 * Applies to all addressable LEDs in the device.
 * Defaults come from platformio.ini.
 */
struct LedHardwareConfigV2 {
  LedType  type  = static_cast<LedType>(LED_TYPE);                ///< defaults to platformio.ini
  LedOrder order = static_cast<LedOrder>(LED_ORDER);              ///< defaults to platformio.ini
};


/**
 * @brief LED configuration (filament strip)
 */
struct LedConfigV2 {
  int      count        = 8;          ///< Number of LEDs
  int      pin          = -1;         ///< GPIO pin
  int      brightness   = 10;         ///< Brightness [0..255]
  int      timeout      = 2000;       ///< Timeout in ms
  uint32_t color        = 0x00FF00;   ///< Default color 0xRRGGBB
  uint32_t colorError   = 0xFF00FF;   ///< Error color 0xRRGGBB
  uint32_t colorPulse   = 0x0040A0;   ///< Idle pulse color 0xRRGGBB
};

/**
 * @brief NFC LED configuration
 */
struct NfcLedConfigV2 {
  int      count                  = 8;          ///< Number of LEDs
  int      pin                    = -1;         ///< GPIO pin
  int      brightness             = 10;         ///< Brightness [0..255]
  int      timeout                = 4000;       ///< Timeout in ms
  uint32_t colorSuccess           = 0x00FF00;   ///< Success color 0xRRGGBB
  uint32_t colorError             = 0xFF0000;   ///< Error color 0xRRGGBB
  uint32_t colorPulse             = 0x0000FF;   ///< Idle pulse color 0xRRGGBB
  bool     successBlinkEnabled    = true;       ///< True = success blinking enabled
  int      successBlinkCount      = 3;          ///< Number of blink cycles
  int      successBlinkMs         = 200;        ///< Blink interval in ms
};

/**
 * @brief Button configuration
 */
struct ButtonConfigV2 {
  bool enabled       = true; ///< Button enabled?
  int  pin           = -1;   ///< Button GPIO (-1 = off)
  bool pullup        = true; ///< Internal pull-up -> active-low
  int  debounceMs    = 30;   ///< Debounce time
  int  longMs        = 800;  ///< Long-press threshold
  int  doubleGapMs   = 400;  ///< Double-press window
  int  holdRepeatMs  = 250;  ///< Hold repeat rate
};

/**
 * @brief Buzzer configuration
 */
struct BuzzerConfigV2 {
  bool enabled       = true;  ///< Buzzer enabled?
  int  pin           = -1;    ///< Buzzer GPIO (-1 = off)
  bool activeHigh    = true;  ///< Active level HIGH?
  bool passive       = false; ///< false = active buzzer, true = passive (PWM)
  int  freqHz        = 4000;  ///< Frequency for tone()
  int  singleMs      = 80;    ///< Duration of single beep
  int  doubleOnMs    = 60;    ///< Duration of one double-beep pulse
  int  doubleGapMs   = 80;    ///< Pause between double-beep pulses
  int  errorOnMs     = 50;    ///< Duration of one error-sequence pulse
  int  errorGapMs    = 60;    ///< Pause between error-sequence pulses
  int  errorCount    = 3;     ///< Number of error-sequence repetitions
};

/**
 * @brief MQTT configuration
 */

struct MqttConfigV2 {
  bool enabled                = false;
  String server               = "192.168.168.150";
  uint16_t port               = 1883;
  String user                 = "";    
  String password             = "";
  String baseTopic            = "spotmyfilament";
  String clientId             = "filament-board";
  bool haDiscovery            = false   ;          ///< Home Assistant discovery active
  String haDiscoveryPrefix    = "homeassistant";  ///< Prefix for HA Discovery (e.g. "homeassistant")
};


/**
 * @brief Filaman configuration
 */
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

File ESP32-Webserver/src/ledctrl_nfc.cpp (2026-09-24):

#include <Arduino.h>
#include <math.h>
#include <LittleFS.h>
#include <ArduinoJson.h>
#include <Adafruit_NeoPixel.h>
#include "ledctrl_nfc.h"
#include "neopixel_guard.h"
#include "pins.h"
#include "led_config.h"

// ============================================================================
// Debug
// ============================================================================
#ifdef LED_NFC_DEBUG
#define DBG(...)                                 \
  do                                             \
  {                                              \
    Serial.printf("[NFCLED][t=%lu] ", millis()); \
    Serial.printf(__VA_ARGS__);                  \
  } while (0)
static const char *stName(uint8_t s)
{
  switch (s)
  {
  case 0:
    return "OFF";
  case 1:
    return "SUCCESS_BLINK";
  case 2:
    return "SUCCESS";
  case 3:
    return "ERROR";
  default:
    return "?";
  }
}
#else
#define DBG(...) \
  do             \
  {              \
  } while (0)
static inline const char *stName(uint8_t) { return ""; }
#endif

// ============================================================================
// Public configuration (via loadNfcLedConfigV2 / config_v2.json)
// ============================================================================
int NFC_LED_COUNT = 8;
int NFC_LED_BRIGHTNESS = 255;
unsigned long NFC_LED_TIMEOUT = 6000; // Timeout in ms (starts after tag removal)

uint32_t NFC_LED_COLOR_SUCCESS = 0x00FF00; // 0xRRGGBB
uint32_t NFC_LED_COLOR_ERROR = 0xFF0000;   // 0xRRGGBB
uint32_t NFC_LED_COLOR_PULSE = 0x0033AA;   // 0xRRGGBB

bool NFC_LED_SUCCESS_BLINK_ENABLED = true;
uint8_t NFC_LED_SUCCESS_BLINK_COUNT = 3;
uint16_t NFC_LED_SUCCESS_BLINK_MS = 150;

// ============================================================================
// Internal state
// ============================================================================
enum LedState : uint8_t
{
  LED_OFF,
  LED_SUCCESS_BLINK,
  LED_SUCCESS,
  LED_ERROR
};
static LedState currentState = LED_OFF;

// --- Blinking (phase-based) ---
static uint8_t s_successBlinkStep = 0;         // Half-steps since start
static bool s_successBlinkOn = false;          // even=ON / odd=OFF
static unsigned long s_blinkStartTs = 0;       // fixed start time (phase anchor)
static uint16_t s_blinkMs = 150;               // active blink interval
static constexpr uint16_t MIN_BLINK_MS = 25;   // lower bound for blink interval
static constexpr uint8_t MAX_BLINK_COUNT = 10; // upper limit for blink cycles

// --- Presence/sticky hold ---
static bool s_tagHeld = false;                 // tag physically present (including grace)
static unsigned long s_lastTagSeen = 0;        // timestamp of the last raw detection
static const uint16_t TAG_HELD_GRACE_MS = 200; // protection against short measurement gaps

// --- Reassert (against half frames / RMT glitches) ---
static bool s_holdActive = false;
static uint32_t s_holdColorNeo = 0; // currently the color that should remain visually stable
static unsigned long s_lastHoldRefresh = 0;
static const uint16_t HOLD_REFRESH_MS = 25; // reassert interval

// --- Timeout (starts only after the tag is removed) ---
static unsigned long s_releaseTs = 0; // 0 = timeout inactive

// --- Idle pulse (breathing) ---
static bool idlePulseEnabled = true;
static float minBrightness = 0.30f; // minimum brightness factor [0..1]
static unsigned long s_lastPulseUpdate = 0;
// FIX: Reduce idle FPS (approximately 40 FPS)
static const uint16_t PULSE_INTERVAL_MS = 25;
static const uint16_t BREATHS_PER_MIN = 15;
static const uint8_t BAYER4[16] = {
    0, 8, 2, 10, 12, 4, 14, 6, 3, 11, 1, 9, 15, 7, 13, 5};
static uint8_t ditherPhase = 0;

// --- Idle blocker (only affects idle) ---
static unsigned long s_idleBlockUntil = 0;

// --- Debounce for success trigger (against duplicate triggers) ---
static unsigned long s_lastSuccessCmdTs = 0;
static const uint16_t SUCCESS_DEBOUNCE_MS = 200;

// FIX: network-load pause (suspend idle frames)
unsigned long LEDCTRL_NFC::s_netPauseUntil = 0;

// standby: all LEDs off, no update (including no idle pulse)
static bool _standby = false;
bool LEDCTRL_NFC::_standby = false;

// ============================================================================
// Strip-Instanz (intern) – implementiert in ledctrl_nfc.h
// ============================================================================
Adafruit_NeoPixel *LEDCTRL_NFC::_leds = nullptr;

// Optionaler Zugriff (nur weiterreichen/lesen)
Adafruit_NeoPixel *LEDCTRL_NFC::rawStrip() { return _leds; }

// ============================================================================
// Helpers (file-scope)
// ============================================================================
static inline int pixCount()
{
  return LEDCTRL_NFC::rawStrip() ? (int)LEDCTRL_NFC::rawStrip()->numPixels() : 0;
}

static inline uint32_t rgbHexToNeo(uint32_t rgb)
{
  const uint8_t r = (rgb >> 16) & 0xFF;
  const uint8_t g = (rgb >> 8) & 0xFF;
  const uint8_t b = rgb & 0xFF;
  return ledColor(LEDCTRL_NFC::rawStrip(), r, g, b);
}

static inline void renderAll(uint32_t neo)
{
  const int n = pixCount();
  for (int i = 0; i < n; ++i)
    LEDCTRL_NFC::rawStrip()->setPixelColor(i, neo);
}

static inline void forceFill(uint32_t neo)
{
  // Send twice (short interval) to avoid glitches/partial frames
  renderAll(neo);
  neopixelShowSafe(LEDCTRL_NFC::rawStrip());
  delayMicroseconds(300);
  neopixelShowSafe(LEDCTRL_NFC::rawStrip());
}

// FIX: generic double-show when there is no full fill (blink/idle/single pixel)
static inline void forceShowNfc()
{
  if (!LEDCTRL_NFC::rawStrip())
    return;
  neopixelShowSafe(LEDCTRL_NFC::rawStrip());
  delayMicroseconds(300);
  neopixelShowSafe(LEDCTRL_NFC::rawStrip());
}

static uint8_t breath8(uint16_t bpm, uint32_t nowMs, uint8_t low, uint8_t high)
{
  const float periodMs = 60000.0f / (float)bpm;
  float phase01 = fmodf((float)nowMs, periodMs) / periodMs;
  float s = (sinf(phase01 * 2.0f * PI) + 1.0f) * 0.5f;
  uint16_t v = (uint16_t)(low + s * (float)(high - low) + 0.5f);
  return (uint8_t)min<uint16_t>(v, 255);
}
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

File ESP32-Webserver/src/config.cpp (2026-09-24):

#include "config.h"
#include <LittleFS.h>
#include <ArduinoJson.h>
#include "ledctrl_filament.h"
#include "ledctrl_nfc.h"
#include "gpio_hardware.h" // for gpiohw_init()
#include "globals.h"
#include "filehandling.h"
#include "pins.h"
#include "filaman_manager.h"
#include "i18n/i18n.h"



AppConfigV2 CONFIGV2;

// migration flag
bool configChanged = false;

// ============================================================================
// Load / apply configuration
// ============================================================================

bool loadConfigV2()
{
    // LittleFS mounten (mit Format-on-fail = true, wie bisher genutzt)
    Serial.println("Mounting LittleFS for V2...");
    Serial.println();
    if (!LittleFS.begin(true))
    {

        Serial.println(F("LittleFS mount failed V2!"));

        // Preserve existing behavior: block
        while (1)
        {
            delay(10);
        }
    }

    if (!LittleFS.exists("/config_v2.json"))
    {
        Serial.println(F("Config file not found!"));
        return false;
    }

    File f = LittleFS.open("/config_v2.json", "r");
    if (!f)
    {
        Serial.println(F("Failed to open config file!"));
        return false;
    }

    JsonDocument doc;
    auto err = deserializeJson(doc, f);
    f.close();
    if (err)
        return false;

    if (!doc.is<JsonObject>())
        return false;

    bool wasMigrated = migrateConfigV2(doc); // check for migration needs

    JsonObject cfg = doc.as<JsonObject>();

    JsonObject sys          = cfg["system"];
    JsonObject ledHardware  = cfg["ledHardware"];
    JsonObject led          = cfg["led"];
    JsonObject nfc          = cfg["nfc"];
    JsonObject btn          = cfg["button"];
    JsonObject buz          = cfg["buzzer"];
    JsonObject mqtt         = cfg["mqttConfig"];
    JsonObject filaman      = cfg["filamanConfig"];

    // --- Version ---
    CONFIGV2.system.version = cfg["version"] | "error";

    // --- Basis-Flags ---
    CONFIGV2.system.darkmode = sys["darkmode"] | false;

    CONFIGV2.system.debugMode = sys["debugMode"] | false;
    CONFIGV2.system.hostname = sys["hostname"] | "FiSaBo";
    CONFIGV2.system.animationAfterBoot = sys["animationAfterBoot"] | true;
    CONFIGV2.system.defaultLanguage = sys["defaultLanguage"] | "en";
    CONFIGV2.system.updateCheckInterval = sys["updateCheckInterval"] | 3; // default 3 Minuten
    CONFIGV2.system.timezone = sys["timezone"] | TIMEZONE; //default germany

    // --- LED-Hardware ---
    const char *ledType = ledHardware["type"] | "WS2812B";
    const char *ledOrder = ledHardware["order"] | "GRB";

    if (CONFIGV2.system.debugMode)
    {
        Serial.println();
        Serial.println("LED-Hardware from JSON:");
        Serial.printf("  type  = '%s'\n", ledType);
        Serial.printf("  order = '%s'\n", ledOrder);
    }

    // LED-Typ
    if (strcmp(ledType, "WS2812B") == 0)
    {
        CONFIGV2.ledHardware.type = LED_TYPE_WS2812B;
    }
    else if (strcmp(ledType, "SK6812_RGB") == 0)
    {
        CONFIGV2.ledHardware.type = LED_TYPE_SK6812_RGB;
    }
    else if (strcmp(ledType, "SK6812_RGBW") == 0)
    {
        CONFIGV2.ledHardware.type = LED_TYPE_SK6812_RGBW;
    }
    else
    {
        CONFIGV2.ledHardware.type = LED_TYPE_WS2812B;
    }

    // LED-Reihenfolge
    if (strcmp(ledOrder, "GRB") == 0)
    {
        CONFIGV2.ledHardware.order = LED_ORDER_GRB;
    }
    else if (strcmp(ledOrder, "RGB") == 0)
    {
        CONFIGV2.ledHardware.order = LED_ORDER_RGB;
    }
    else if (strcmp(ledOrder, "GRBW") == 0)
    {
        CONFIGV2.ledHardware.order = LED_ORDER_GRBW;
    }
    else
    {
        CONFIGV2.ledHardware.order = LED_ORDER_GRB;
    }

    // --- Filament-LED ---
    CONFIGV2.led.count = led["count"] | 8;
    CONFIGV2.led.brightness = led["brightness"] | 50;
    CONFIGV2.led.timeout = led["timeout"] | 3000;
    // --- Dashboard (Virtuelle LED)---
    CONFIGV2.system.webLEDTimeout = sys["webLEDTimeout"] | (uint32_t)CONFIGV2.led.timeout; // Fallback auf ledTimeout

    if (led["ledColor"].is<JsonArray>())
    {
        JsonArray c = led["ledColor"];
        CONFIGV2.led.color = ((uint32_t)c[0] << 16) | ((uint32_t)c[1] << 8) | (uint32_t)c[2];
    }
    else
    {
        CONFIGV2.led.color = 0xFFFFFF;
    }

    if (led["ledColorError"].is<JsonArray>())
    {
        JsonArray e = led["ledColorError"];
        CONFIGV2.led.colorError = ((uint32_t)e[0] << 16) | ((uint32_t)e[1] << 8) | (uint32_t)e[2];
    }
    else
    {
        CONFIGV2.led.colorError = 0xFF0000;
    }

    if (led["ledColorPulse"].is<JsonArray>())
    {
        JsonArray p = led["ledColorPulse"];
        CONFIGV2.led.colorPulse = ((uint32_t)p[0] << 16) | ((uint32_t)p[1] << 8) | (uint32_t)p[2];
    }
    else
    {
        CONFIGV2.led.colorPulse = 0x0000FF;
    }

    // --- NFC-LED ---
    CONFIGV2.nfc.count = nfc["count"] | 8;
    CONFIGV2.nfc.brightness = nfc["brightness"] | 100;
    CONFIGV2.nfc.timeout = nfc["timeout"] | 4000;
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

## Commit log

2025-12-03 Add initial ideas for electronics and CAD projects
2025-12-06 Files added
    [PN532_NFC_Assembly.STEP]
2025-12-06 CAD Files added //Kolja
    [Adafruit_NeoPixel_Stick_8.step, OLED13_IIC.stp]
2025-12-06 Add new Files //Kolja
    [CDU_Kolja_V1.stp, ESP32-C3.step]
2025-12-06 Inital upload
    [FilamentSampleRegal v10.f3d, FilamentSampleRegal v10.step, FilamentSampleRegal.f3d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]
2025-12-07 Upload ESP Code
    [A1-mini.3mf, LED-Halter.step, ModifiedSample.3mf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]
2025-12-09 Functional version: NFC + OLED + LED timeout working
2025-12-09 Functional version: NFC + OLED + LED timeout working, WebIF partly working
2025-12-10 Functional version: NFC + OLED + LED timeout working, WebIF mainly working
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2025-12-12 working version
    [partitions_ota_littlefs.csv]
2025-12-13 Update CAD
    [OLED 2.42 V1.1 SSD1309.STEP]
2025-12-13 Zurück
    [OLED 2.42 V1.1 SSD1309.STEP]
2025-12-13 Backup zurück
    [221-2411.stp, Adafruit_NeoPixel_Stick_8.step, ESP32-C3.step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]
2025-12-13 Enhance display functionality with text adjustments
    Refactor display handling to support umlaut replacement and dynamic text fitting.
    [display.cpp]
2025-12-13 Fix for small displays (SCREEN_HEIGHT <= 32)
    [display.cpp]
2025-12-13 Fix #2 for small displays (SCREEN_HEIGHT <= 32)
    [display.cpp]
2025-12-13 Fix #3 FINAL for small displays (SCREEN_HEIGHT <= 32)
    [display.cpp]
2025-12-13 Restore Fix #3 FINAL for small displays (SCREEN_HEIGHT <= 32)
    [display.cpp]
2025-12-13 Update CDU Case Design (larger housing + pushbutton)
2025-12-14 Add new NFC tag holder
    [SampleFuss_V2.0.stp]
2025-12-15 Fix: Standby pulse effect (smooth breathing)
    [ledctrl_nfc.cpp]
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2025-12-16 implement new, centralized config handling for NFC LED colors and blink settings
2025-12-17 change config to setting, improve websocket stability
    [my_webserver.cpp]
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2025-12-17 filehandling fix for Filament
    [filehandling.cpp, my_webserver.cpp]
2025-12-17 index.html, style.js und style.css angepasst, um das Grid-Layout für die Filament-Kacheln zu definieren.
2025-12-17 Restore CAD-Files from feature/dev-kolja
    [CDU_Kolja_V3_Final_ESP32_Plate.3mf, CDU_Kolja_V3_Final_ESP32_Plate.stp, CDU_Kolja_V3_Final_Frontplatte.3mf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]
2025-12-17 Update CAD Files
    [CDU_Kolja_V3_USB_Cover.stl]
2025-12-19 Add: Buzzer , Pushbutton + Config Update
    [filehandling.cpp, gpio_hardware.cpp, main.cpp]
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2025-12-20 Fix: Config display (bootscreen) , Add: Reboot handler by button
    [display.cpp, gpio_hardware.cpp, main.cpp]
2025-12-21 fixed reboot handler in webserver
    [main.cpp, my_webserver.cpp]
2025-12-22 update fix2 webserver + leds
    [ledctrl_filament.cpp, ledctrl_nfc.cpp, main.cpp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]
2025-12-22 webLED handling fix + config update
    [filehandling.cpp, ledctrl_filament.cpp, my_webserver.cpp]
2025-12-23 complete rebuild (config handling) / WebIF Dashboard fixes
    [filehandling.cpp, gpio_hardware.cpp, main.cpp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]
2026-01-03 try adding pin defeinitions for S3 and C3
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2026-01-10 OTA Update for "My Filament Sample Board"
    [partitions_ota_littlefs_esp32dev.csv, partitions_ota_littlefs_esp32s3.csv]
2026-01-12 Fix esp32dev + default PINS + bugfix in main.cpp
    [partitions_ota_littlefs_esp32dev.csv]
2026-01-14 OTA improvements, UI tweaks, and bug fixes
    [main.cpp, my_webserver.cpp]
2026-02-08 Anpassung Webif und MQTT für die neue Filamentdatenbank
2026-02-11 Implement mqtt enable/disable via config, add startup delay for better stability, and include config header in gpio_hardware.cpp to avoid potential issues with missing config values.
    [config.cpp, config.h, display.cpp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]
2026-02-14 additionally, the following files have been modified: - ESP32-S3-Filament-Webserver/data/index.html - ESP32-S3-Filament-Webserver/include/globals.h - ESP32-S3-Filament-Webserver/include/version_info.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
2026-02-15 changes in webinterface: added day/night mode toggle, which is saved in config and applied on load. Also added a slider for the web interface LED timeout, which is also saved in config. Updated the w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
2026-02-15 small fix for update check display (test only, not really checking for updates yet)
    [config.cpp]
2026-02-19 various changes - language selection for web interface - added german translation - added i18n helper for web interface - added option to disable boot animation (not working) - added check for board 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
    [config.cpp, config.h, main.cpp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]
2026-03-03 Remove pin configuration from web interface and hardcode it in firmware, as the pinout is fixed for the sample board. This simplifies the web interface and reduces potential user errors in configurat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
    [config.cpp, config.h, gpio_hardware.cpp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]
2026-04-20 bugfixing the display of the version information on the web interface and adding a new version number for the next release.
    [partitions_ota_littlefs_esp32dev.csv]
2026-04-22 Work on ST7789 display initialization and error display. Added getMaxTextSize() to calculate the maximum text size that fits within a given width.
    [display.cpp, display_st7789.h, main.cpp]
2026-08-26 Documentation for the Smart Filament Sample Board project. Startet bugfixing OLED Display.
    [display_oled.cpp]
2026-08-26 Add 'WORK IN PROGRESS' note to 3D print documentation
2026-08-26 Fix OLED display initialization and add color definitions for TFT displays.
    [display_config.h, display_oled.cpp]
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2026-08-27 Fix pin config error, add variants for SH1106 and SSD1306 displays, update firmware version to v0.4.2
    [gpio_hardware.cpp]
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2026-08-28 Fix NFC initialization issue for S3 variants. The previous implementation was not compatible with the S3 architecture, leading to failures during NFC initialization. This commit updates the NFC initi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
    [display_oled.cpp, main.cpp]
2026-08-28 FIX pin names for SPI interface in platformio.ini and add SPI defines to the build flags for all environments.
    [main.cpp]
2026-08-29 Recently edited files: ESP32-Webserver/data/settings.html ESP32-Webserver/data/settings.js ESP32-Webserver/include/pins.h ESP32-Webserver/include/version_info.h ESP32-Webserver/platformio.ini ESP32-W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
    Rename pin definitions for TFT and NFC SPI connections.
    Fix WebIF pin tables for changed pin definitions.
    [display_st7789.h, main.cpp, my_webserver.cpp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]
2026-08-30 Updated 3D files an screenshots for new version also move files for better overwiev
    [A1-mini.3mf, Filament-Sample-Board_6x.3mf, Filament-Sample-Board_7x.3mf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]
2026-08-30 added screenshots for documentation and a sample 3mf file for the foot model
    [Sample_Fuss.3mf]
2026-08-30 Enhance 3D printing documentation
    Updated the 3D printing documentation with file and printing settings details.
2026-08-30 Fix image paths and typo in 3D print documentation
    Updated image paths to use relative links and corrected a typo in the text.
2026-08-30 Fix typos in 3D printing instructions
2026-08-30 Update links and descriptions in 3D print documentation
2026-08-30 Improve 3D print documentation with formatting updates
    Enhanced formatting and added details for 3D printing instructions.
2026-08-30 Prepare for different LED types (SK6812 RGBW, SK6812 RGB, WS2812B) and different LED orders (GRB, RGB, etc.) by adding a new header file `led_config.h` and modifying the `platformio.ini` build flags 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
2026-09-01 Added new LED hardware type and color order settings to the web interface. Updated language files to reflect these changes in both German and English. Adjusted JavaScript to handle the new settings a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
2026-09-01 Default to WS2812B and GRB for LED hardware type and color order in the configuration and settings files. Update the UI to reflect these defaults and ensure that the correct options are displayed bas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
2026-09-06 Begin implement success green blink on LEDs after successful OTA update. This is a follow-up to the previous commit that implemented the reboot countdown and error indication on LEDs. Now, when the f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
    [ledctrl_filament.cpp, main.cpp, my_webserver.cpp]
2026-09-08 If debug is disabled, only few information messages will be printed to serial out. Also green blink if FW update was succesfully completed.
2026-09-08 Removed possibility to update littlefs via WebIF changes on config.json or filaments.json will now be migrated by the ESP32 firmware itself, no need to update littlefs via WebIF anymore. Tried to aut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
    [config.cpp, config.h, display_config.h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]
2026-09-10 Lots of changes Start adding time sync Added debug Version for local update server testing Changed libraris for tzapu/WiFiManager @ ^2.0.5 ESP32Async/AsyncTCP @ ^3.4.10 ESP32Async/ESPAsyncWebServer @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
2026-09-10 created dev-release.py to be able to fully check build chain inkl. self updates and webinstaller
2026-09-11 Webserver static files now embedded pre script embed_assets.py will read webfiles from ./web_assets and auto include in web_asstes_generated.h Only config_v2.json and filaments.json will be left in l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
    [my_webserver.cpp]
2026-09-11 see previous commit, somehow missing
    [config.cpp]
2026-09-16 Filaman API / update check / bugfixing Fixed bug in i18n.cpp after switching lang_de.json and lang_en.json from littlefs to embdedded. Change update check from version.txt to github api call Begin im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
    [FilamanClient.h, config.h, filaman_manager.cpp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]
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2026-09-16 Create English README for Smart Filament Sample Board
    Add README_EN.md with project details and documentation.
2026-09-22 Add documentation for local DB vs FilaMan workflow
    This document outlines the workflow and decision logic for using the local `filaments.json` database versus the live FilaMan database, including synchronization mechanisms and operational details.
2026-09-22 Add usage instructions for Filaman integration
    Document usage instructions for integrating with Filaman, including NFC tag setup, sample retrieval, and Home Assistant control.
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2026-09-22 Add usage documentation for board operations
    Added usage instructions for the board's web interface and Home Assistant integration, including sample finding and control features.
2026-09-22 Revise local DB usage instructions and remove outdated sections
    Updated the local usage documentation to clarify operations with local DB and NFC tag handling. Removed sections on web interface sample finding and Home Assistant control.
2026-09-22 Add overview section to 3D printing documentation
    Added a brief overview section for 3D printing parts.
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2026-09-23 Filaman Sync Fix default values for possible broken config Factory Reset now per WebIf possible Issues: FilamanSync sometimes unsuccessfull Update check failes with Response length: 0
    [partitions_ota_littlefs_esp32dev.csv, partitions_ota_littlefs_esp32s3.csv]
2026-09-24 Revert update check to version.txt github json to heavy and requires to much code change otherwise ESP will bekome instable und unreliable begin implementing debug out with millis or timestamp
    [FilamanClient.h, filaman_manager.cpp, ledctrl_filament.cpp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]
